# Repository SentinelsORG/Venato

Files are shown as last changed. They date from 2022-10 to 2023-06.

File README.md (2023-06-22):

# Project Venato

## What is "Venato"?

"**Venato**" is a piece of hardware that provides affordable surveillance and protection to people. The main focus of this project is to **showcase our skills in PCB design, circuit design, and RF design**. Additionally, we have taken this opportunity to create something useful for society.

<ins>**The Problem We Are Addressing**</ins>

Most surveillance systems in the market are expensive and require a complex installation procedure. At the time of developing this device, CCTV systems did not have a machine learning model to detect theft or danger. Do you have a protection or tracking system for your personal belongings, such as your wallet, travel bags, vehicle, or pets?

<ins>**The Basic Idea of Our Solution**</ins>

"Venato" is a modular device, meaning it consists of a main module (Venato Board) and other optional modules. Buyers can select the features they desire and obtain the necessary modules. The system can be upgraded using these modules. The main module (Venato) houses all the computing power, battery, and features like GPS and GPRS. The base module includes the charging station and cameras. Additionally, we are developing a few extra modules that provide additional features for this setup. The main module (i.e. Venato) is a credit card sized PCB that we designed specially for the ease of carrying. At the moment, we are still developing this module to be more compact, more featurestic and user friendly.

## Schematic Design

Please find below a brief explanation of the schematic design. I have included a screenshot of the schematic design for your reference, which is attached below. Additionally, you can access the PDF version of the schematic through the following link:

Link: [https://github.com/SentinelsORG/Venato/blob/main/documentation/schematic.pdf](https://github.com/SentinelsORG/Venato/blob/main/documentation/schematic.pdf)

The schematic illustrates the electronic design of the main PCB (Venato). As depicted, we have utilized ESP32 and SIM808 chips to provide our PCB with all the necessary functionalities. Furthermore, you can observe the incorporation of meticulous design techniques aimed at enhancing the reliability and fail-safe nature of our product.

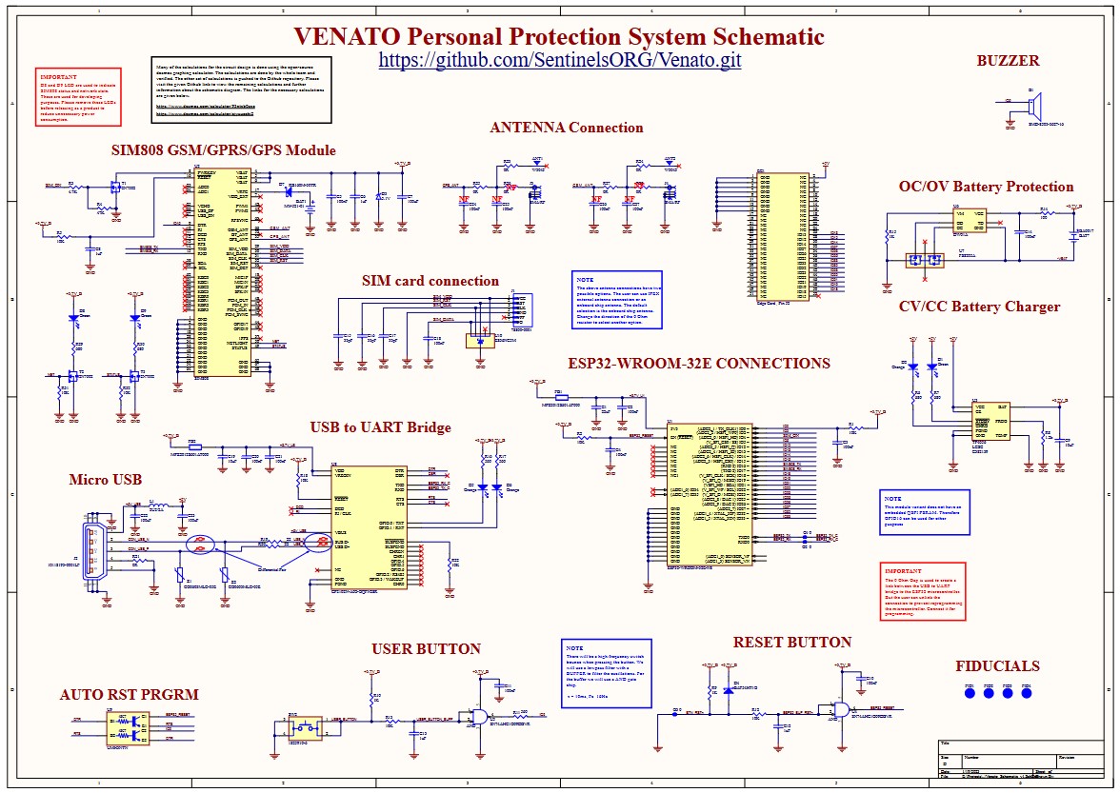
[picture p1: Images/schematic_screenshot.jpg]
Screen shot of the Schematic PDF

In addition to the previously mentioned schematic design of the main PCB, please note that we have also developed separate PCBs for the other modules. You can access the schematic designs for these modules in the provided repository.

## PCB Design

In addition to the schematic design, we have invested considerable effort in designing the PCB for this project. In this PCB design, meticulous attention has been given to the placement of each capacitor and resistor. Furthermore, we have diligently calculated the trace impedance and ensured its compatibility with the antennas employed for GPS and GSM/GPRS. A screenshot of the 2D view of the PCB design, created using Altium software, is provided below. For the original PCB and schematic designs, please refer to the corresponding repository on GitHub.

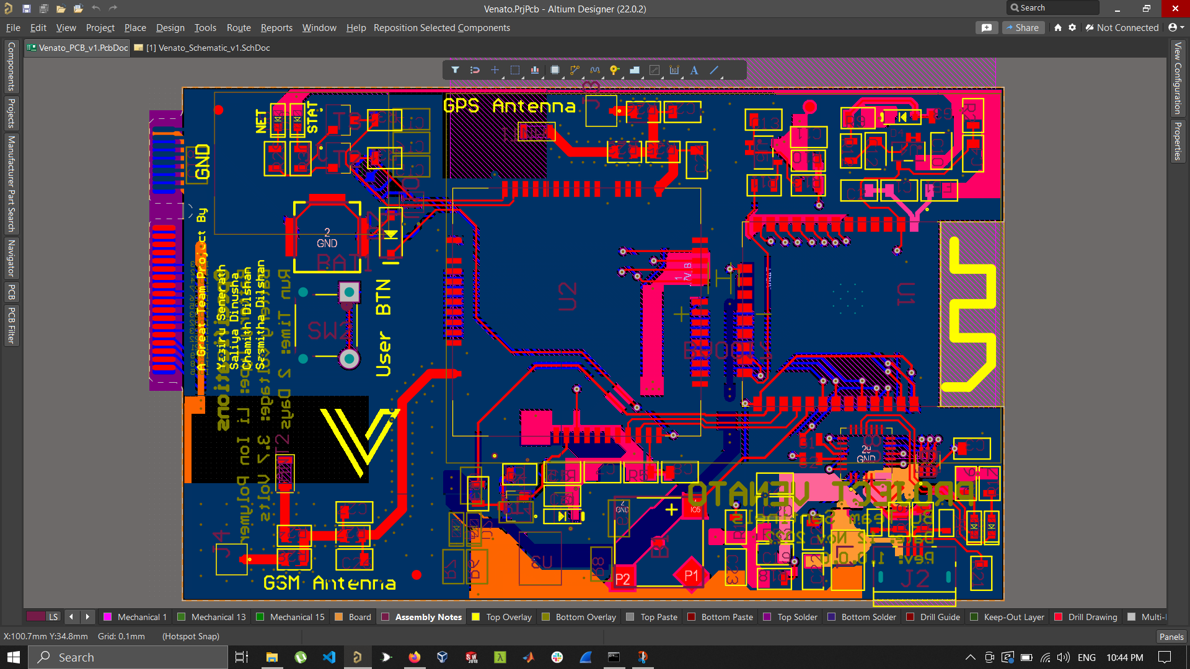
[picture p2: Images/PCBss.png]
Screen shot of 2D PCB


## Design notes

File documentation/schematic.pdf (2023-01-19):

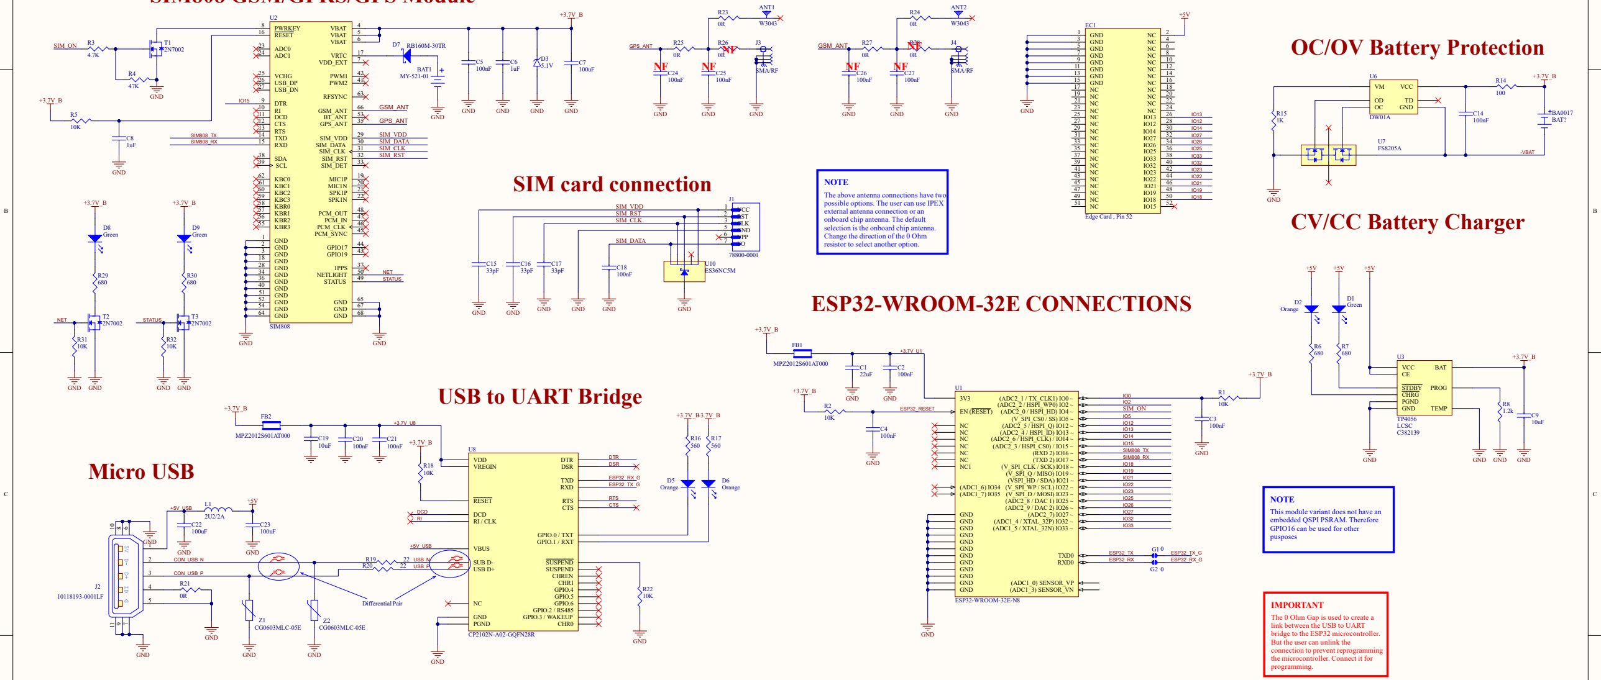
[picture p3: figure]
EN (RESET); (ADC1_0) SENSOR_VP (ADC1_3) SENSOR_VN; (ADC1_6) IO34 (ADC1_7) IO35; TXD0 RXD0; (ADC2_1 / TX_CLK1) IO0 ~; (ADC2_2 / HSPI_WP0) IO2 ~ (ADC2_0 / HSPI_HD) IO4 ~ (V_SPI_CS0 / SS) IO5 ~ (ADC2_5 / HSPI_Q) IO12 ~ (ADC2_4 / HSPI_ID) IO13 ~ (ADC2_6 / HSPI_CLK) / IO14 ~ (ADC2_3 / HSPI_CS0) / IO15 ~ (RXD 2) IO16 ~ (TXD 2) IO17 ~ (V_SPI_CLK / SCK) IO18 ~ (V_SPI_Q / MISO) IO19 ~ (VSPI_HD / SDA) IO21 ~ (V_SPI_WP / SCL) IO22 ~ (V_SPI_D / MOSI) IO23 ~ (ADC2_8 / DAC 1) IO25 ~ (ADC2_9 / DAC 2) IO26 ~ (ADC2_7) IO27 ~ (ADC1_4 / XTAL_32P) IO32 ~ (ADC1_5 / XTAL_32N) IO33 ~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
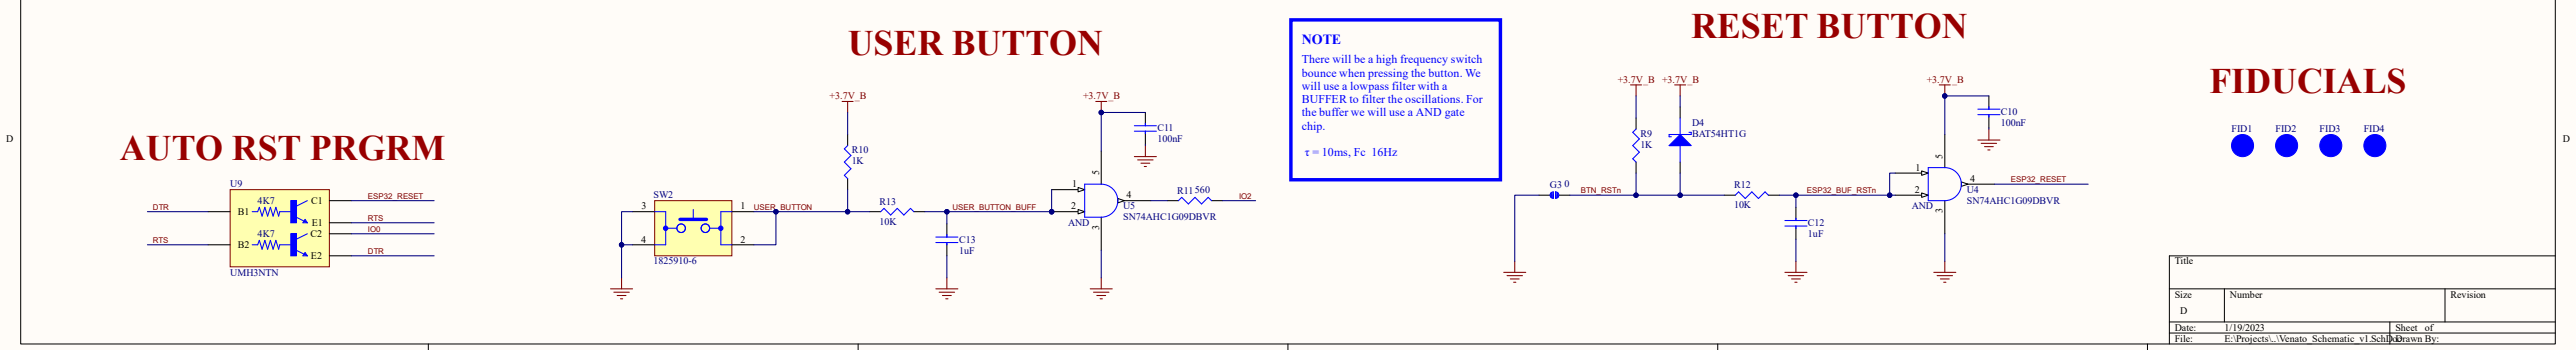
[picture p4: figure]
Title; Size; Number; Revision; Date:; Sheet of; File:; E:\Projects\..\Venato_Schematic_v1.SchDocDrawn By:; AND; U4 SN74AHC1G09DBVR; D4 BAT54HT1G; BTN_RSTn; ESP32_BUF_RSTn; ESP32_RESET; RESET BUTTON; U5 SN74AHC1G09DBVR; USER_BUTTON; USER_BUTTON_BUFF; USER BUTTON; FID1; FID2; FID3; FID4; FIDUCIALS; There will be a high frequency switch bounce when pressing the button. We will use a lowpass filter with a BUFFER to filter the oscillations. For the buffer we will use a AND gate chip.; NOTE; UMH3NTN; DTR; RTS; AUTO RST PRGRM

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
# SIM808 GSM/GPRS/GPS Module

# VENATO Personal Protection System Schematic

# https://github.com/SentinelsORG/Venato.git

# BUZZER

IO5

GND

# ANTENNA Connection

### D8 and D9 LED are used to indicate

SIM808 status and network state.

### These are used for developing purposes. Please remove these LEDs before releasing as a product to reduce unnecessary power

consumption.

## IMPORTANT

Many of the calculations for the circuit design is done using the open-source desmos graphing calculator. The calculations are done by the whole team and verified. The other set of calculations is pushed to the Github repository. Please visit the given Github link to view the remaining calculations and further information about the schematic diagram. The links for the necessary calculations

are given below.

### https://www.desmos.com/calculator/93ntxb0axe https://www.desmos.com/calculator/zjyuuzehi2

+

B1

SMD-8503-3627-16

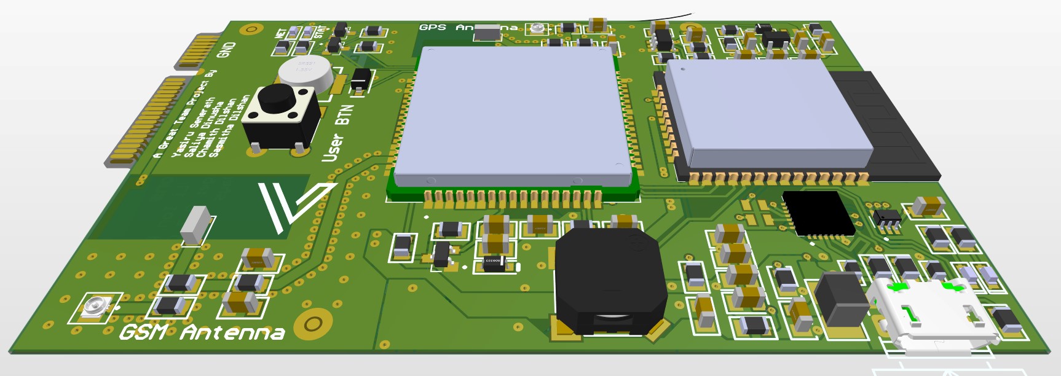
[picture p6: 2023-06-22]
Images/pcb 3D.jpg

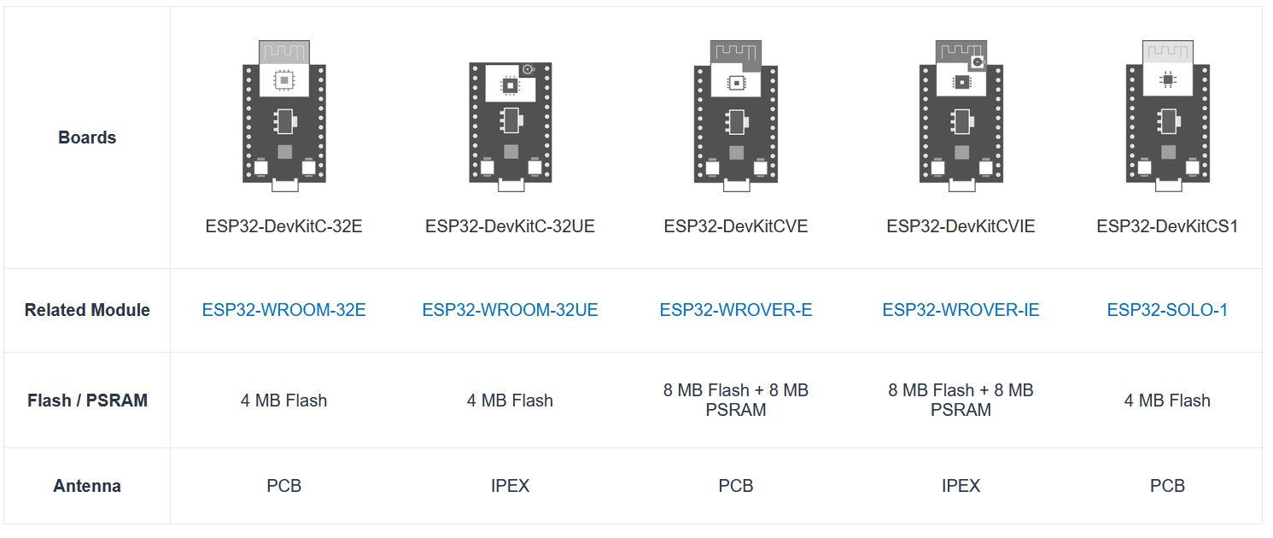
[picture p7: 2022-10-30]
Images/ESP32 Devkits.jpg

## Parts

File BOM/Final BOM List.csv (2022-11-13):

LCSC Part Number | Manufacture Part Number | Manufacturer | Package | Order Qty. | Min\Mult Order Qty. | Unit Price | Order Price | Description | Product Link
C2832999 | GD25Q80ESIG | GigaDevice Semicon Beijing | SOP-8-208mil | 1 | 1 | $0.46 | $0.46 | 2.7V~3.6V -40℃~85℃ 8Mbit 133MHz SOP-8-208mil NOR FLASH ROHS | https://assets.lcsc.com/images/lcsc/96x96/20210526_GigaDevice-Semicon-Beijing-GD25Q80ESIG_C2832999_front.jpg
C3019597 | W3043 | Pulse Elec | - | 2 | 1 | $1.52 | $3.05 | Chip antenna Vertical 50Ω - Antennas ROHS | https://assets.lcsc.com/images/lcsc/96x96/20220623_Pulse-Elec-W3043_C3019597_front.jpg
C2685545 | SMD-8503-3627-16Ω | S&S | SMD | 1 | 1 | $0.35 | $0.35 | SMD Buzzers ROHS | https://assets.lcsc.com/images/lcsc/96x96/20210121_S-S-SMD-8503-3627-16R_C2685545_front.jpg
C964848 | MY-521-01 | MYOUNG | SMD | 4 | 1 | $0.16 | $0.64 | Battery button SR521 SMD Battery Connectors ROHS | https://assets.lcsc.com/images/lcsc/96x96/20201222_MYOUNG-MY-521-01_C964848_front.jpg
C45783 | CL21A226MAQNNNE | Samsung Electro-Mechanics | 805 | 20 | 20 | $0.02 | $0.45 | 25V 22uF X5R ±20% 0805 Multilayer Ceramic Capacitors MLCC - SMD/SMT ROHS | https://assets.lcsc.com/images/lcsc/96x96/20190222_Samsung-Electro-Mechanics-CL21A226MAQNNNE_C45783_front.jpg
C77083 | GRM21BR71H105KA12L | Murata Electronics | 805 | 10 | 10 | $0.05 | $0.51 | 50V 1uF X7R ±10% 0805 Multilayer Ceramic Capacitors MLCC - SMD/SMT ROHS | https://assets.lcsc.com/images/lcsc/96x96/20180914_Murata-Electronics-GRM21BR71H105KA12L_C77083_front.jpg
C141660 | GRM21BR60J107ME15L | Murata Electronics | 805 | 3 | 1 | $0.40 | $1.21 | 6.3V 100uF X5R ±20% 0805 Multilayer Ceramic Capacitors MLCC - SMD/SMT ROHS | https://assets.lcsc.com/images/lcsc/96x96/20180914_Murata-Electronics-GRM21BR60J107ME15L_C141660_front.jpg
C107115 | CC0805JRNPO9BN330 | YAGEO | 805 | 100 | 100 | $0.01 | $0.77 | 50V 33pF NP0 ±5% 0805 Multilayer Ceramic Capacitors MLCC - SMD/SMT ROHS | https://assets.lcsc.com/images/lcsc/96x96/20200926_YAGEO-CC0805JRNPO9BN330_C107115_front.jpg
C21107 | BAT54HT1G | onsemi | SOD-323 | 10 | 10 | $0.05 | $0.51 | 30V 800mV@100mA 200mA SOD-323 Schottky Barrier Diodes (SBD) ROHS | https://assets.lcsc.com/images/lcsc/96x96/20190622_onsemi-BAT54HT1G_C21107_front.jpg
C183502 | RB160M-30TR | ROHM Semicon | SOD-123 | 5 | 5 | $0.10 | $0.50 | 30V 480mV@1A 1A SOD-123 Schottky Barrier Diodes (SBD) ROHS | https://assets.lcsc.com/images/lcsc/96x96/20180921_ROHM-Semicon-RB160M-30TR_C183502_front.jpg
C21519 | MPZ2012S601AT000 | TDK | 805 | 10 | 10 | $0.05 | $0.52 | 2A 1 100mΩ 600Ω@100MHz ±25% 0805 Ferrite Beads ROHS | https://assets.lcsc.com/images/lcsc/96x96/20180914_TDK-MPZ2012S601AT000_C21519_front.jpg
C127364 | 788000001 | MOLEX | SMD | 1 | 1 | $0.70 | $0.70 | Clamshell 1.5mm Deck MicroSIM card SMD SIM Card Connectors ROHS | https://assets.lcsc.com/images/lcsc/96x96/20180914_MOLEX-788000001_C127364_front.jpg
C132562 | 10118193-0001LF | Amphenol ICC | SMD | 3 | 1 | $0.23 | $0.69 | USB 2.0 1 Surface Mount 5 Female Micro-B SMD USB Connectors ROHS | https://assets.lcsc.com/images/lcsc/96x96/20180914_Amphenol-ICC-10118193-0001LF_C132562_front.jpg
C84376 | RC0805FR-0710KL | YAGEO | 805 | 200 | 100 | $0.00 | $0.46 | 125mW 150V ±100ppm/℃ ±1% -55℃~+155℃ 10kΩ 0805 Chip Resistor - Surface Mount ROHS | https://assets.lcsc.com/images/lcsc/96x96/20180914_YAGEO-RC0805FR-0710KL_C84376_front.jpg
C105427 | RC0805JR-074K7L | YAGEO | 805 | 100 | 100 | $0.00 | $0.20 | 125mW Thick Film Resistors 150V ±100ppm/℃ ±5% -55℃~+155℃ 4.7kΩ 0805 Chip Resistor - Surface Mount ROHS | https://assets.lcsc.com/images/lcsc/96x96/20180914_YAGEO-RC0805JR-074K7L_C105427_front.jpg
C131051 | RC0805JR-0747KL | YAGEO | 805 | 100 | 100 | $0.00 | $0.18 | 125mW Thick Film Resistors 150V ±100ppm/℃ ±5% -55℃~+155℃ 47kΩ 0805 Chip Resistor - Surface Mount ROHS | https://assets.lcsc.com/images/lcsc/96x96/20180914_YAGEO-RC0805JR-0747KL_C131051_front.jpg
C114526 | RC0805FR-071K2L | YAGEO | 805 | 100 | 100 | $0.00 | $0.23 | 125mW Thick Film Resistors 150V ±100ppm/℃ ±1% -55℃~+155℃ 1.2kΩ 0805 Chip Resistor - Surface Mount ROHS | https://assets.lcsc.com/images/lcsc/96x96/20180914_YAGEO-RC0805FR-071K2L_C114526_front_10.jpg
C95781 | RC0805FR-071KL | YAGEO | 805 | 100 | 100 | $0.00 | $0.23 | 125mW Thick Film Resistors 150V ±100ppm/℃ ±1% -55℃~+155℃ 1kΩ 0805 Chip Resistor - Surface Mount ROHS | https://assets.lcsc.com/images/lcsc/96x96/20210929_YAGEO-RC0805FR-071KL_C95781_front.jpg
C114536 | RC0805FR-07560RL | YAGEO | 805 | 100 | 100 | $0.00 | $0.23 | 125mW Thick Film Resistors 150V ±100ppm/℃ ±1% -55℃~+155℃ 560Ω 0805 Chip Resistor - Surface Mount ROHS | https://assets.lcsc.com/images/lcsc/96x96/20180914_YAGEO-RC0805FR-07560RL_C114536_front_10.jpg
C105577 | RC0805FR-07100RL | YAGEO | 805 | 100 | 100 | $0.00 | $0.23 | 125mW 150V ±100ppm/℃ ±1% -55℃~+155℃ 100Ω 0805 Chip Resistor - Surface Mount ROHS | https://assets.lcsc.com/images/lcsc/96x96/20180914_YAGEO-RC0805FR-07100RL_C105577_front.jpg
C107702 | RC0805FR-0722RL | YAGEO | 805 | 100 | 100 | $0.00 | $0.23 | 125mW Thick Film Resistors 150V ±100ppm/℃ ±1% -55℃~+155℃ 22Ω 0805 Chip Resistor - Surface Mount ROHS | https://assets.lcsc.com/images/lcsc/96x96/20180914_YAGEO-RC0805FR-0722RL_C107702_front_10.jpg
C96345 | RC0805JR-070RL | YAGEO | 805 | 100 | 100 | $0.00 | $0.19 | 125mW Thick Film Resistors 150V -55℃~+155℃ 0Ω 0805 Chip Resistor - Surface Mount ROHS | https://assets.lcsc.com/images/lcsc/96x96/20211015_YAGEO-RC0805JR-070RL_C96345_front.jpg
C428628 | 1825910-6 | TE Connectivity | Plugin | 5 | 5 | $0.07 | $0.33 | 6mm 5mm Round Button 50mA Straight 6mm SPST 24V Plugin Tactile Switches ROHS | https://assets.lcsc.com/images/lcsc/96x96/20191010_TE-Connectivity-1825910-6_C428628_front.jpg
C701342 | ESP32-WROOM-32E-N8 | Espressif Systems | SMD38,18x25.5x3.1 | 3 | 1 | $3.19 | $9.58 | SMD38,18x25.5x3.1 WiFi Modules ROHS | https://assets.lcsc.com/images/lcsc/96x96/20200727_Espressif-Systems-ESP32-WROOM-32E-N8_C701342_front.jpg
C126275 | SIM808 | SIMCom Wireless Solutions | SMD Module | 3 | 1 | $9.38 | $28.14 | SMD Module 2G/3G/4G/5G Modules ROHS | https://assets.lcsc.com/images/lcsc/96x96/20180914_SIMCom-Wireless-Solutions-SIM808_C126275_front.jpg
C725790 | TP4056 | UMW(Youtai Semiconductor Co., Ltd.) | ESOP-8 | 5 | 5 | $0.08 | $0.41 | ESOP-8 Battery Management ICs ROHS | https://assets.lcsc.com/images/lcsc/96x96/20200822_UMW-Youtai-Semiconductor-Co---Ltd--TP4056_C725790_front.jpg
C840099 | SN74AHC1G09DBVR | Texas Instruments | SOT-23-5 | 2 | 1 | $0.32 | $0.65 | 74AHC 2V~5.5V 1uA 2 1 And SOT-23-5 Gates ROHS | https://assets.lcsc.com/images/lcsc/96x96/20200919_Texas-Instruments-SN74AHC1G09DBVR_C840099_front.jpg
C351410 | DW01A | PUOLOP | SOT-23-6L | 10 | 10 | $0.04 | $0.37 | SOT-23-6L Battery Management ICs ROHS | https://assets.lcsc.com/images/lcsc/96x96/20190109_PUOLOP-DW01A_C351410_front.jpg
C16052 | FS8205A | Fortune Semicon | TSSOP-8(3x4.4x0.65） | 5 | 5 | $0.24 | $1.21 | 20V 6A 25mΩ@4.5V,4A 1W 1V@250uA 2 N-Channel TSSOP-8(3x4.4x0.65） MOSFETs ROHS | https://assets.lcsc.com/images/lcsc/96x96/20180914_Fortune-Semicon-FS8205A_C16052_front.jpg
C964632 | CP2102N-A02-GQFN28R | SILICON LABS | QFN-28 | 1 | 1 | $2.69 | $2.69 | QFN-28 USB ICs ROHS | https://assets.lcsc.com/images/lcsc/96x96/20220920_SILICON-LABS-CP2102N-A02-GQFN28R_C964632_front.jpg
C123008 | UMH3NTN | ROHM Semicon | SOT-363 | 5 | 5 | $0.07 | $0.33 | 2 NPN - Pre-Biased 150mW 100mA 50V SOT-363 Digital Transistors ROHS | https://assets.lcsc.com/images/lcsc/96x96/20180914_ROHM-Semicon-UMH3NTN_C123008_front.jpg
C2960985 | ES36NC5M | JESTEK | SOT-363 | 10 | 10 | $0.04 | $0.35 | SOT-363 ESD Protection Devices ROHS | https://assets.lcsc.com/images/lcsc/96x96/20220407_JESTEK-ES36NC5M_C2960985_front.jpg
C840634 | CG0603MLC-05E | BOURNS | 603 | 5 | 5 | $0.20 | $0.99 | 30V 0.2pF@1MHz 5V 0603 Varistors ROHS | https://assets.lcsc.com/images/lcsc/96x96/20210402_BOURNS-CG0603MLC-05E_C840634_front.jpg
C83055 | 0805B104K500CT | Walsin Tech Corp | 805 | 50 | 50 | $0.01 | $0.32 | 50V 100nF X7R ±10% 0805 Multilayer Ceramic Capacitors MLCC - SMD/SMT ROHS | https://assets.lcsc.com/images/lcsc/96x96/20200709_Walsin-Tech-Corp-0805B104K500CT_C83055_front.jpg
C2174205 | TMK212BJ105KD-T | Taiyo Yuden | 805 | 20 | 20 | $0.03 | $0.60 | 25V 1uF X5R ±10% 0805 Multilayer Ceramic Capacitors MLCC - SMD/SMT ROHS | https://assets.lcsc.com/images/lcsc/96x96/20220311_Taiyo-Yuden-TMK212BJ105KD-T_C2174205_front.jpg
C109040 | GRM21BC71E106KE11L | Murata Electronics | 805 | 50 | 5 | $0.08 | $4.23 | 25V 10uF X7S ±10% 0805 Multilayer Ceramic Capacitors MLCC - SMD/SMT ROHS | https://assets.lcsc.com/images/lcsc/96x96/20200318_Murata-Electronics-GRM21BC71E106KE11L_C109040_front.jpg
C5137310 | TC0603GF01-1CSA | TCWIN | 603 | 50 | 50 | $0.02 | $0.80 | Green 2.6V~3V 0603 Light Emitting Diodes (LED) ROHS | https://assets.lcsc.com/images/lcsc/96x96/20221107_TCWIN-TC0603GF01-1CSA_C5137310_front.jpg
C434425 | SZYY0603O | Yongyu Photoelectric | 603 | 50 | 50 | $0.01 | $0.57 | 10mA 612nm Colorless transparence -40℃~+85℃ 598nm~608nm Orange 120° 40mW 0603 Light Emitting Diodes (LED) ROHS | https://assets.lcsc.com/images/lcsc/96x96/20191211_Yongyu-Photoelectric-SZYY0603O_C434425_front.jpg
C2904813 | BZT52C5V1S | YONGYUTAI | SOD-323 | 50 | 50 | $0.02 | $0.78 | 2uA@2V 60Ω 5.1V~5.4V 200mW 5.1V SOD-323 Zener Diodes ROHS | https://assets.lcsc.com/images/lcsc/96x96/20211016_YONGYUTAI-BZT52C5V1S_C2904813_front.jpg
C92980 | CBC3225T2R2MR | Taiyo Yuden | 1210 | 5 | 5 | $0.10 | $0.48 | 1.13A 2.2uH ±20% 2A 104mΩ 1210 Inductors (SMD) ROHS | https://assets.lcsc.com/images/lcsc/96x96/20180914_Taiyo-Yuden-CBC3225T2R2MR_C92980_front.jpg
C2771101 | CQ05W8F6800T5E | UNI-ROYAL(Uniroyal Elec) | 805 | 100 | 100 | $0.00 | $0.37 | 125mW ±100ppm/℃ ±1% -55℃~+155℃ 680Ω 0805 Chip Resistor - Surface Mount ROHS | https://assets.lcsc.com/images/lcsc/96x96/20221008_UNI-ROYAL-Uniroyal-Elec-CQ05W8F6800T5E_C2771101_front.jpg
C382335 | 2N7002K | KEXIN | SOT-23 | 20 | 20 | $0.02 | $0.44 | 60V 300mA 2Ω@10V,500mA 350mW 2.5V@1mA N Channel SOT-23 MOSFETs ROHS | https://assets.lcsc.com/images/lcsc/96x96/20190704_KEXIN-2N7002K_C382335_front.jpg
C2987682 | IPEX-1 | ZIISOR | SMD | 10 | 10 | $0.05 | $0.51 | SMD RF Connectors / Coaxial Connectors ROHS | https://assets.lcsc.com/images/lcsc/96x96/20220710_ZIISOR-IPEX-1_C2987682_front.jpg
C565575 | FN21N180J500PAG | PSA(Prosperity Dielectrics) | 805 | 50 | 50 | $0.01 | $0.32 | 50V 18pF C0G ±5% 0805 Multilayer Ceramic Capacitors MLCC - SMD/SMT ROHS | https://assets.lcsc.com/images/lcsc/96x96/20201121_PSA-Prosperity-Dielectrics-FN21N180J500PAG_C565575_front.jpg
C336527 | EEE1AA101WR | PANASONIC | SMD,D5xL5.4mm | 5 | 5 | $0.21 | $1.03 | -40℃~+85℃ 2000hrs@85℃ 100uF 5.4mm 10V 5mm ±20% SMD,D5xL5.4mm Aluminum Electrolytic Capacitors - SMD ROHS | https://assets.lcsc.com/images/lcsc/96x96/20221012_PANASONIC-EEE1AA101WR_C336527_front.jpg
C428486 | 1775862-2 | TE Connectivity | SMD,P=0.8mm | 2 | 1 | $0.52 | $1.04 | 0.8mm Surface Mount 52 SMD,P=0.8mm Card Edge Connectors ROHS | https://assets.lcsc.com/images/lcsc/96x96/20191011_TE-Connectivity-1775862-2_C428486_front.jpg
C124384 | B-2100S06P-B110 | Ckmtw(Shenzhen Cankemeng) | Straight,P=2.54mm | 10 | 10 | $0.04 | $0.39 | Straight 2.54mm 6mm -40℃~+105℃ 2 3mm 6 2.54mm Black Brass 2x3P 2.54mm Straight,P=2.54mm Pin Headers ROHS | https://assets.lcsc.com/images/lcsc/96x96/20180914_Ckmtw-Shenzhen-Cankemeng-B-2100S06P-B110_C124384_front.jpg
C202111 | DM3CS-SF | HRS(Hirose) | SMD | 1 | 1 | $0.94 | $0.94 | Deck MicroSD card (TF card) Pluggable SMD SD Card Connectors ROHS | https://assets.lcsc.com/images/lcsc/96x96/20180914_HRS-Hirose-DM3CS-SF_C202111_front.jpg
C132125 | DS1023-2*9SF11 | CONNFLY Elec | Straight,P=2.54mm | 2 | 1 | $0.16 | $0.32 | 2.54mm 2.54mm Straight 2x9P 18 2 Straight,P=2.54mm Female Headers ROHS | https://assets.lcsc.com/images/lcsc/96x96/20180914_CONNFLY-Elec-DS1023-2-9SF11_C132125_front.jpg
C168677 | 68000-103HLF | Amphenol ICC | Straight,P=2.54mm | 3 | 1 | $0.23 | $0.69 | Straight Square Pins 2.54mm 1 2.54mm Black Phosphor bronze Straight,P=2.54mm Pin Headers ROHS | https://assets.lcsc.com/images/lcsc/96x96/20180914_Amphenol-ICC-68000-103HLF_C168677_front.jpg
C96346 | RC0805FR-07100KL | YAGEO | 805 | 100 | 100 | $0.00 | $0.23 | 125mW 150V ±100ppm/℃ ±1% -55℃~+155℃ 100kΩ 0805 Chip Resistor - Surface Mount ROHS | https://assets.lcsc.com/images/lcsc/96x96/20190628_YAGEO-RC0805FR-07100KL_C96346_front.jpg
C107700 | RC0805FR-071ML | YAGEO | 805 | 100 | 100 | $0.00 | $0.24 | 125mW 150V ±100ppm/℃ ±1% -55℃~+155℃ 1MΩ 0805 Chip Resistor - Surface Mount ROHS | https://assets.lcsc.com/images/lcsc/96x96/20180914_YAGEO-RC0805FR-071ML_C107700_front_10.jpg
C132230 | ATMEGA328PB-AU | Microchip Tech | TQFP-32_7x7x08P | 1 | 1 | $2.59 | $2.59 | TQFP-32_7x7x08P Microcontroller Units (MCUs/MPUs/SOCs) ROHS | https://assets.lcsc.com/images/lcsc/96x96/20221017_Microchip-Tech-ATMEGA328PB-AU_C132230_front.jpg
C173386 | AMS1117-3.3V | Shenzhen Fuman Elec | SOT-223 | 5 | 5 | $0.06 | $0.32 | 75dB@(10kHz) 800mA 1.5V@(700mA) Fixed 3.3V~3.3V Positive 1 12V SOT-223 Linear Voltage Regulators (LDO) ROHS | https://assets.lcsc.com/images/lcsc/96x96/20220413_Shenzhen-Fuman-Elec-AMS1117-3-3V_C173386_front.jpg
C596821 | ABLS-16.000MHZ-B4-T | Abracon LLC | HC-49S-SMD-2P | 2 | 1 | $0.32 | $0.65 | 16MHz 18pF 40Ω ±30ppm ±50ppm -20℃~+70℃ HC-49S-SMD-2P Crystals ROHS | https://assets.lcsc.com/images/lcsc/96x96/20220325_Abracon-LLC-ABLS-16-000MHZ-B4-T_C596821_front.jpg
 |  |  |  |  | SUB TOTAL |  | $75.45

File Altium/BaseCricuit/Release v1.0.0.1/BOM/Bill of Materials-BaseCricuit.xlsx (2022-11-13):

 | Bill of Materials
 |  |  |  |  |  |  | 2175 Salk Avenue
 | Project Title: | Bill of Materials for Project [BaseCricuit.PrjPcb] (No PCB Document Selected) |  |  |  |  | Suite 200
 | Project File Name: | BaseCricuit.PrjPcb |  |  |  |  | Carlsbad, CA 92008
 | Assembly Variant: | None |  |  |  |  | USA
Part Number | Description | Designator | Manufacture | Manufacture Part Number | Supplier | Supplier Part Number | Supplier Unit Price | Quantity
CGA4J2X7R1H104K125AM | Cap Ceramic 0.1uF 50V X7R 10% Pad SMD 0805 125°C Automotive T/R | C1, C3, C6, C8 | TDK | CGA4J2X7R1H104K125AM | Digi-Key | 445-6958-1-ND | $0.20 | 4
CGA4J3X7S1A106M125AB | Cap Ceramic 10uF 10V X7S 20% Pad SMD 0805 125°C Low ESR Automotive T/R | C2, C4, C5 | TDK | CGA4J3X7S1A106M125AB | Digi-Key | 445-16115-1-ND | $0.41 | 3
C0805C180J5GACTU | Cap Ceramic 18pF 50V C0G 5% SMD 0805 125C Paper T/R | C7, C9 | KEMET | C0805C180J5GACTU | Digi-Key | 399-C0805C180J5GAC7800CT-ND | $0.11 | 2
EEE-1AA101WR | Cap Aluminum 100uF 10V 20% (5 X 5.4mm) SMD 50mA 1000 hr 85°C T/R | C10, C11, C12, C13 | Panasonic | EEE-1AA101WR | RSComponents | 1763738 |  | 4
RB160M-30TR | DIODE SCHOTTKY 30V 1A PMDU | D1 |  |  |  |  |  | 1
MPZ2012S601AT000 | Ferrite Beads Multi-Layer Power 600Ohm 25% 100MHz 2A 100mOhm DCR 0805 T/R | FB1, FB2 | TDK | MPZ2012S601AT000 | Digi-Key | 445-2206-6-ND |  | 2
0Ohm gap | This is a gap that diconects line. you can connect it using soldier | G1, G2 |  |  |  |  |  | 2
1775862-2 | MSATA/MINI PCI-E 5.2H TYPE I G/F | J1, J2 | TE Connectivity | 1775862-2 | RSComponents | 2411326P |  | 2
SCREW_TERMINAL | SCREW_TERMINAL | J3 |  |  |  |  |  | 1
67997-106HLF | Conn Unshrouded Header HDR 6 POS 2.54mm Solder ST Top Entry Thru-Hole BergStik® Bulk | J4, J6 | Amphenol Communications Solutions | 67997-106HLF | Newark | 06M1758 | $0.68 | 2
DM3CS-SF | Connector, Memory, Micro Sd, Hinged Rohs Compliant: Yes | J5 | Hirose | DM3CS-SF | RSComponents | 7726787 |  | 1
10118193-0001LF | FCI Right Angle Surface Mount Mount Female USB Connector; 100 V ac; 1.8A | J7 | Amphenol Communications Solutions | 101181930001LF | Digi-Key | 609-4616-1-ND | $0.45 | 1
PPTC092LFBN-RC | Connector Header 18 Position 0.100" (2.54mm) Tin Through Hole | J8 | Sullins | PPTC092LFBN-RC | Digi-Key | S7077-ND | $1.09 | 1
68000-103HLF | Conn Unshrouded Header HDR 3 POS 2.54mm Solder ST Top Entry Thru-Hole BergStik® Automotive Bulk | JP1 | Amphenol Communications Solutions | 68000-103HLF | Allied Electronics | 70236888 | $0.28 | 1
L1210R2R2MDWIT | Inductor RF Chip Wirewound 2.2uH 20% 100KHz 1.13A 0.104Ohm DCR 1210 T/R | L1 | KEMET | L1210R2R2MDWIT | Digi-Key | 399-9598-1-ND | $0.48 | 1
RC0805JR-074K7L | Res Thick Film 0805 4.7K Ohm 5% 0.125W(1/8W) ±100ppm/C Pad SMD T/R | R1, R10, R11 |  |  | RSComponents |  |  | 3
RC0805FR-07100KL | Res Thick Film 0805 100K Ohm 1% 1/8W ±100ppm/°C Molded SMD Paper T/R | R2 | Yageo | RC0805FR-07100KL | RSComponents | 1995648 |  | 1
RC0805FR-0722RL | Res SMD 0805 22R 1% 0.125W T.C.100PPM | R3 | Yageo | RC0805FR-0722RL | Digi-Key | 311-22.0CRCT-ND | $0.10 | 1
RC0805FR-0710KL | Res SMD 0805 10K 1% 0.125W T.C.100PPM | R4, R5, R6, R9 | Yageo | RC0805FR-0710KL | Digi-Key | 311-10.0KCRTR-ND |  | 4
RC0805FR-071ML | Res Thick Film 0805 1M Ohm 1% 0.125W(1/8W) ±100ppm/C Pad SMD T/R | R7 | Yageo | RC0805FR-071ML | Digi-Key | 311-1.00MCRCT-ND | $0.10 | 1
RC0805JR-070RL | RC Series 0805 0.125 W 0 Ohm Jumper Surface Mount Thick Film Chip Resistor | R8 | Yageo | RC0805JR-070RL | Digi-Key | 311-0.0ARCT-ND | $0.10 | 1
Relay |  | RE1 |  |  |  |  |  | 1
2N7002 | Transistor Mosfet N-ch 60V 0.3A 3-PIN SOT-23 T/r | T1 |  |  |  |  |  | 1
ATMEGA328PB-AU | IC MCU 8BIT 32KB FLASH 32TQFP | U1 | Microchip | ATMEGA328PB-AU | Mouser | 556-ATMEGA328PB-AU | $1.72 | 1
AMS1117-3.3 | Fixed Positive LDO Regulator, 3.3V, 1.3V Dropout, PDSO3 | U2 | Advanced Monolithic Systems | AMS1117-3.3 | LCSC | C6186 |  | 1
ABLS-16.000MHZ-B4-T | Crystal 16MHz ±30ppm (Tol) ±50ppm (Stability) 18pF FUND 40Ohm 2-Pin HC-49/US SMD T/R | Y1 | Abracon | ABLS-16.000MHZ-B4-T | RSComponents | 1710560 |  | 1
 |  |  |  |  |  |  | $5.72 | 44
Approved |  | Notes

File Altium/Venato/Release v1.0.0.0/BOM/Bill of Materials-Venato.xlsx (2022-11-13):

 | Bill of Materials
 |  |  |  |  |  |  | 2175 Salk Avenue
 | Project Title: | Bill of Materials for Project [Venato.PrjPcb] (No PCB Document Selected) |  |  |  |  | Suite 200
 | Project File Name: | Venato.PrjPcb |  |  |  |  | Carlsbad, CA 92008
 | Assembly Variant: | None |  |  |  |  | USA
Part Number | Description | Designator | Manufacture | Manufacture Part Number | Supplier | Supplier Part Number | Supplier Unit Price | Quantity
W3043 | Antenna Ceramic Monopole 4dB Gain 2483.5MHz SMD | ANT1, ANT2 | Pulse | W3043 | Digi-Key | 553-W3043CT-ND | $1.59 | 2
SMD-8503-3627-16 | SMD Buzzers ROHS | B1 | S&S | SMD-8503-3627-16 | LCSC | C2685545 | $0.33 | 1
BA0017 | 3.7V 1200mAh Lipo Battery. Dimension: 40.0±3.0mm x 30.0±2.0mm 8.0±0.5mm (1.575±0.118" x 1.181±0.079" x 0.315±0.020") | BA0017 |  |  |  |  |  | 1
MY-521-01 | Battery button SR521 SMD Battery Connectors ROHS | BAT1 | MYoung | MY-521-01 | LCSC | C964848 | $0.16 | 1
CL21A226MAQNNNE | CAP CER 22UF 25V X5R 0805 | C1 | Samsung | CL21A226MAQNNNE | LCSC | C45783 |  | 1
CGA4J2X7R1H104K125AM | Cap Ceramic 0.1uF 50V X7R 10% Pad SMD 0805 125°C Automotive T/R | C2, C3, C4, C5, C10, C11, C14, C18, C20, C21, C24, C25, C26, C27 | TDK | CGA4J2X7R1H104K125AM | Digi-Key | 445-6958-1-ND | $0.14 | 14
GRM21BR71H105KA12L | 0805 1 uF 50 V ±10% Tolerance X7R Multilayer Ceramic Chip Capacitor | C6 |  |  | Newark |  |  | 1
GRM21BR60J107ME15L | 0805 100 uF 6.3 V ±20% Tolerance X5R Multilayer Ceramic Chip Capacitor | C7, C22, C23 | Murata | GRM21BR60J107ME15L | Digi-Key | 490-13981-1-ND | $1.15 | 3
C2012X5R1E105K125AA | TDK - C2012X5R1E105K125AA - SMD Multilayer Ceramic Capacitor, 1 µF, 25 V, 0805 [2012 Metric], ± 10%, X5R, C Series | C8, C12, C13 | TDK | C2012X5R1E105K125AA | Digi-Key | 445-1419-1-ND | $0.21 | 3
CGA4J3X7S1A106M125AB | Cap Ceramic 10uF 10V X7S 20% Pad SMD 0805 125°C Low ESR Automotive T/R | C9, C19 | TDK | CGA4J3X7S1A106M125AB | Digi-Key | 445-16115-1-ND | $0.41 | 2
CC0805JRNPO9BN330 | Cap Ceramic 33pF 50V C0G 5% SMD 0805 125C T/R | C15, C16, C17 | Yageo | CC0805JRNPO9BN330 | Digi-Key | 311-1105-1-ND | $0.10 | 3
LGL29K-G2J1-24-Z | LED Single Chip Green 570nm 20mA 2-Pin 0603 T/R | D1, D8, D9 | Osram Opto | LGL29K-G2J1-24-Z | Bison Technologies | LGL29K-G2J1-24-Z-299157-OSRAMOPTO |  | 3
LOL29K-H2K1-24-Z | Smartled Orange Lc | D2, D5, D6 | Osram Opto | LOL29K-H2K1-24-Z | Arrow Electronics | LO L29K-H2K1-24-Z |  | 3
BZT52C5V1S | Zener Single Diode, 5.1 V, 200 Mw, Sod-323, 6 %, 2, 150 C Rohs Compliant: Yes | D3 | Multicomp | BZT52C5V1S | Farnell | 1466019 |  | 1
BAT54HT1G | Small Signal Schottky Diode, Single, 30 V, 200 Ma, 800 Mv, 600 Ma, 150 C | D4 | ON Semiconductor / Fairchild | BAT54HT1G | Digi-Key | BAT54HT1GOSDKR-ND | $0.24 | 1
RB160M-30TR | DIODE SCHOTTKY 30V 1A PMDU | D7 |  |  |  |  |  | 1
EdgeCard |  | EC1 |  |  |  |  |  | 1
MPZ2012S601AT000 | Ferrite Beads Multi-Layer Power 600Ohm 25% 100MHz 2A 100mOhm DCR 0805 T/R | FB1, FB2 | TDK | MPZ2012S601AT000 | Digi-Key | 445-2206-6-ND |  | 2
0Ohm gap | This is a gap that diconects line. you can connect it using soldier | G1, G2, G3 |  |  |  |  |  | 3
78800-0001 | Vertical Surface Mount Memory & SIM Card Connector; with SMT Termination | J1 |  |  | RSComponents |  |  | 1
10118193-0001LF | FCI Right Angle Surface Mount Mount Female USB Connector; 100 V ac; 1.8A | J2 | Amphenol Communications Solutions | 101181930001LF | Digi-Key | 609-4616-1-ND | $0.45 | 1
Ipex | SMD RF Connectors / Coaxial Connectors ROHS | J3, J4 |  |  |  |  |  | 2
L1210R2R2MDWIT | Inductor RF Chip Wirewound 2.2uH 20% 100KHz 1.13A 0.104Ohm DCR 1210 T/R | L1 | KEMET | L1210R2R2MDWIT | Digi-Key | 399-9598-1-ND | $0.48 | 1
RC0805FR-0710KL | Res SMD 0805 10K 1% 0.125W T.C.100PPM | R1, R2, R5, R12, R13, R18, R22, R31, R32 | Yageo | RC0805FR-0710KL | Digi-Key | 311-10.0KCRTR-ND |  | 9
RC0805JR-074K7L | Res Thick Film 0805 4.7K Ohm 5% 0.125W(1/8W) ±100ppm/C Pad SMD T/R | R3 |  |  | RSComponents |  |  | 1
RC0805JR-0747KL | Res Thick Film 0805 47K Ohm 5% 1/8W Ý100ppm/ÝC SMD Paper T/R | R4 |  |  | Arrow Electronics |  |  | 1
RMCF0805JT680R | Res Thick Film 0805 680 Ohm 5% 0.125W(1/8W) ±200ppm/C Pad SMD Automotive T/R | R6, R7, R29, R30 | Stackpole Electronics | RMCF0805JT680R | Digi-Key | RMCF0805JT680RCT-ND | $0.10 | 4
RC0805FR-071K2L | Res Thick Film 0805 1.2K Ohm 1% 0.125W(1/8W) ±100ppm/C Pad SMD T/R | R8 | Yageo | RC0805FR-071K2L | Mouser | 603-RC0805FR-071K2L | $0.10 | 1
RC0805FR-071KL | Res Thick Film 0805 1KOhm 1% 0.125W(1/8W) 100ppm/C Epoxy Pad SMD T/R | R9, R10, R15 | Yageo | RC0805FR-071KL | Digi-Key | 311-1.00KCRTR-ND |  | 3
RC0805FR-07560RL | Res General Purpose Thick Film 0805 560 Ohm 1% 1/8W ±100ppm/°C Molded Paper T/R | R11, R16, R17 | Yageo | RC0805FR-07560RL | Digi-Key | 311-560CRCT-ND | $0.10 | 3
RC0805FR-07100RL | Res Thick Film 0805 100 Ohm 1% 1/8W ±100ppm/°C Molded SMD Paper T/R | R14 | Yageo | RC0805FR-07100RL | Mouser | 603-RC0805FR-07100RL | $0.13 | 1
RC0805FR-0722RL | Res SMD 0805 22R 1% 0.125W T.C.100PPM | R19, R20 | Yageo | RC0805FR-0722RL | Digi-Key | 311-22.0CRCT-ND | $0.10 | 2
RC0805JR-070RL | RC Series 0805 0.125 W 0 Ohm Jumper Surface Mount Thick Film Chip Resistor | R21, R23, R24, R25, R26, R27, R28 | Yageo | RC0805JR-070RL | Digi-Key | 311-0.0ARCT-ND | $0.10 | 7
1825910-6 | Switch Tactile OFF (ON) SPST Round Button PC Pins 0.05A 24VDC 1.57N Thru-Hole Loose | SW2 | TE Connectivity | FSM4JH | Digi-Key | 450-1650-ND | $0.13 | 1
2N7002 | Transistor Mosfet N-ch 60V 0.3A 3-PIN SOT-23 T/r | T1, T2, T3 |  |  |  |  |  | 3
ESP32-WROOM-32E-N8 | 2.4 GHz WiFi + Bluetooth ® + Bluetooth LE module Built around ESP32 series of SoCs, Xtensa® dualcore 32bit LX6 microprocessor 4/8/16 MB flash available 26 GPIOs, rich set of peripherals Onboard PCB antenna or external antenna connector | U1 | Espressif Systems | ESP32-WROOM-32E-N8 | Digi-Key | 1965-ESP32-WROOM-32E-N8CT-ND | $3.30 | 1
SIM808 | GSM/GPRS + GPS + Bluetooth Module SIM808 S2-1060C-Z1F05 SIMCOM; 850/900/1800/1900MHz | U2 |  |  |  |  |  | 1
TP4056 | Res Thick Film 0805 1.2K Ohm 1% 0.125W(1/8W) ±100ppm/C Pad SMD T/R | U3 | TPOWER | TP4056 | LCSC | C382139 |  | 1
SN74AHC1G09DBVR | Single 2-input, 2-V to 5.5-V AND gate with open-drain outputs 5-SOT-23 -55 to 125 | U4, U5 | Texas Instruments | SN74AHC1G09DBVR | Digi-Key | 296-29202-1-ND |  | 2
DW01A | SOT-23-6L Battery Management ICs ROHS | U6 | TF | DW01A | LCSC | C436931 |  | 1
FS8205A | 输入电容(Ciss@Vds)：466pF 10V 反向传输电容(Crss@Vds)：58pF 10V 功率(Pd)：1.5W 阈值电压(Vgs(th)@Id)：700mV 250uA 导通电阻(RDS(on)@Vgs,Id)：19.5mΩ 4.5V,3A 栅极电荷(Qg@Vgs)：5.7nC 10V 漏源电压(Vdss)：20V 连续漏极电流(Id)：6A 工作温度(最大值)：+150℃ (Tj) 工作温度(最小值)：-55℃ (Tj) 类型：2个N沟道 | U7 | Tech Public | FS8205A | LCSC | C2830320 |  | 1
CP2102N-A02-GQFN28R | Full Speed USB to UART Bridge USB 2.0 3.3V T/R Automotive 28-Pin QFN EP | U8 | Silicon Labs | CP2102N-A02-GQFN28R | Mouser | 634-CP2102NA02QFN28R | $2.27 | 1
UMH3NTN | TRANS 2NPN PREBIAS 0.15W UMT6 | U9 | Rohm | UMH3NTN | Digi-Key | UMH3NTNCT-ND | $0.48 | 1
ES36NC5M | SOT-363 ESD Protection Devices ROHS | U10 | JESTEK | ES36NC5M | LCSC | C2960985 |  | 1
CG0603MLC-05E | ESD Suppressor Multilayer Varistor 5V Automotive 2-Pin Case 0603(1608Metric) T/R | Z1, Z2 | Bourns | CG0603MLC-05E | Digi-Key | CG0603MLC-05ETR-ND |  | 2
 |  |  |  |  |  |  | $12.07 | 100
Approved |  | Notes

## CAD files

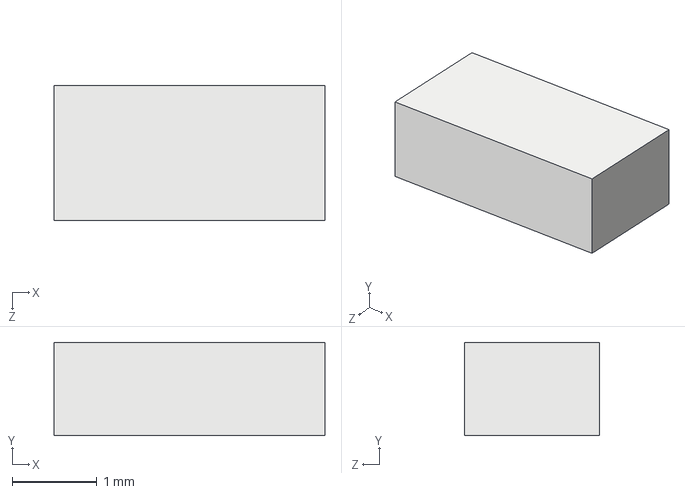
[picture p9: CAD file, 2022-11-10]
3d Models/w3043.STEP
3.20 x 1.10 x 1.60 mm

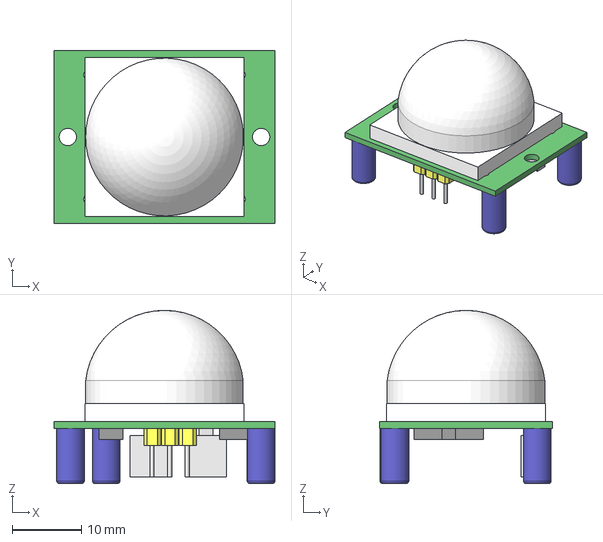
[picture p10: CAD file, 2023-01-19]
Solidworks/Base_part/HCSR501.step
32.0 x 25.0 x 25.1 mm

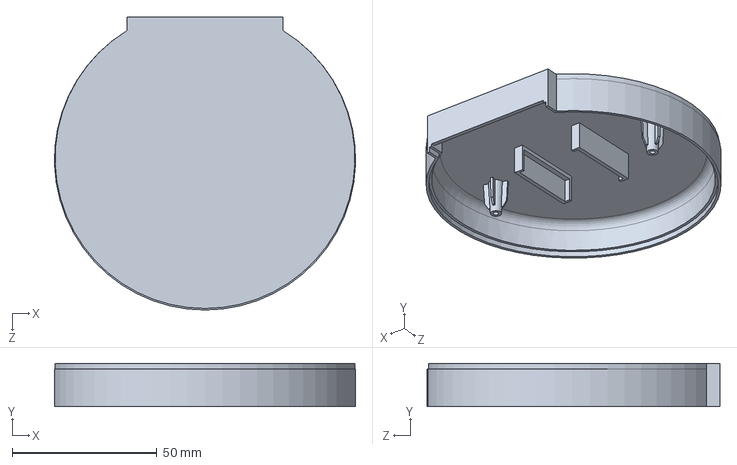
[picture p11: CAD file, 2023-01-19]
Solidworks/Venato_part/venato_top.SLDPRT
103.9 x 15.0 x 101.2 mm

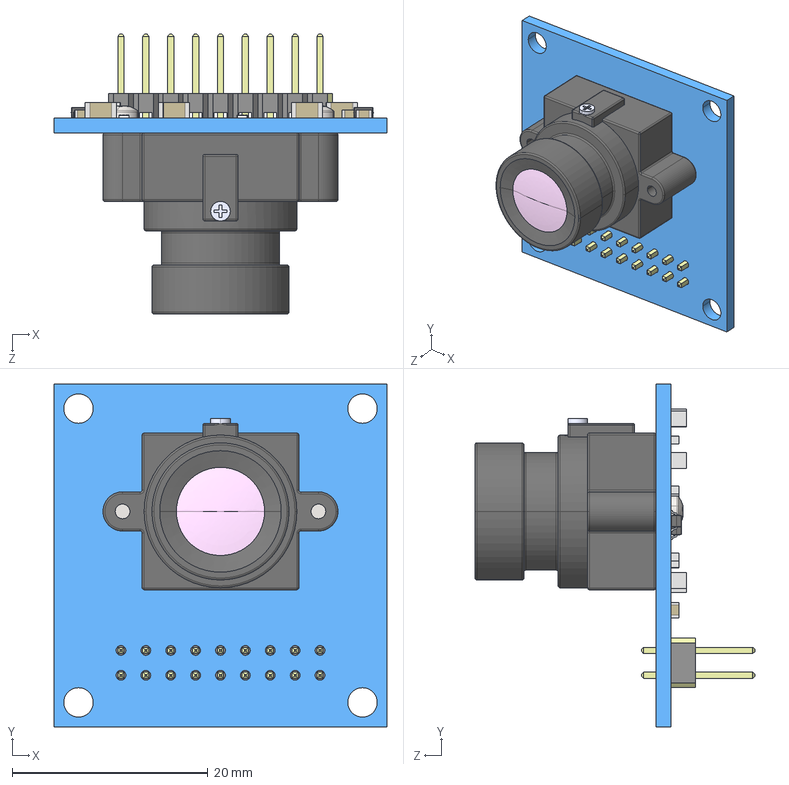
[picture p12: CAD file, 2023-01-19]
Solidworks/Base_part/Camera OV7670.STEP
34.0 x 35.0 x 28.6 mm
PcbForCamera
CameraLens
pan head cross recess screw_iso_ISO 7045 - M1.6 x 6 - Z - 6N x 2
PLS (DS1021-2xN)_DS1021-2x9
CAP 1206_�� 㬮�砭�� x 5
CAP 0603_�� 㬮�砭�� x 6
Stackpole CSR0402 Res_�� 㬮�砭�� x 3
SC-70-5_�� 㬮�砭�� x 2

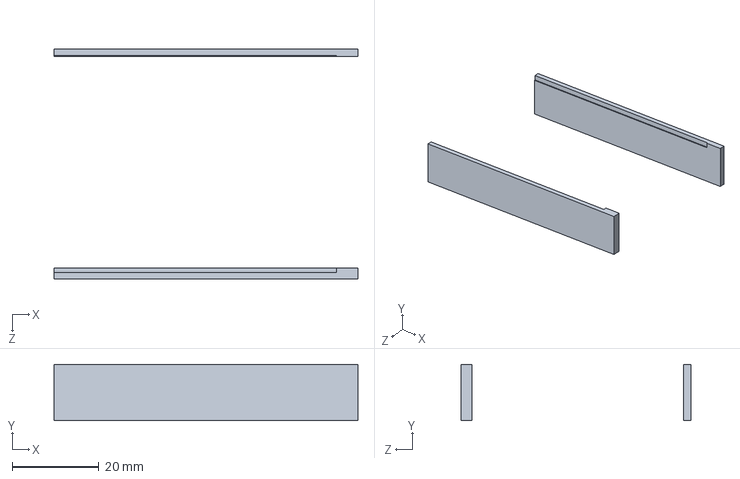
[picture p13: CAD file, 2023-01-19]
Solidworks/Venato_part/venato_pcb_holder.SLDPRT
70.0 x 13.0 x 53.0 mm

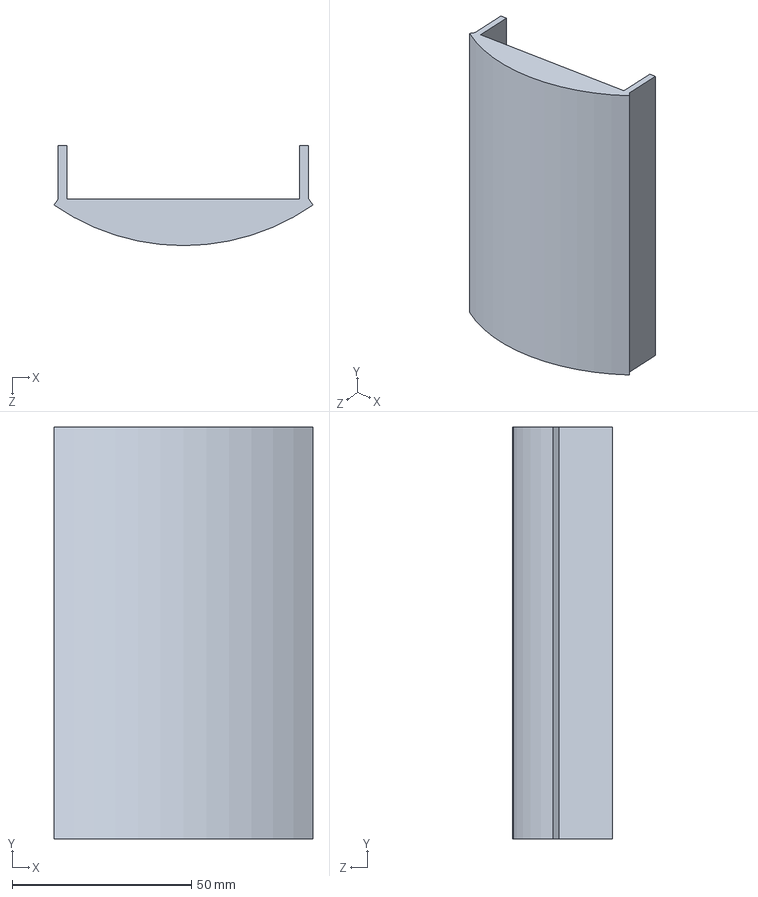
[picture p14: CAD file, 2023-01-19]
Solidworks/Base_part/Base_solidworks_top.SLDPRT
72.3 x 115.0 x 28.0 mm

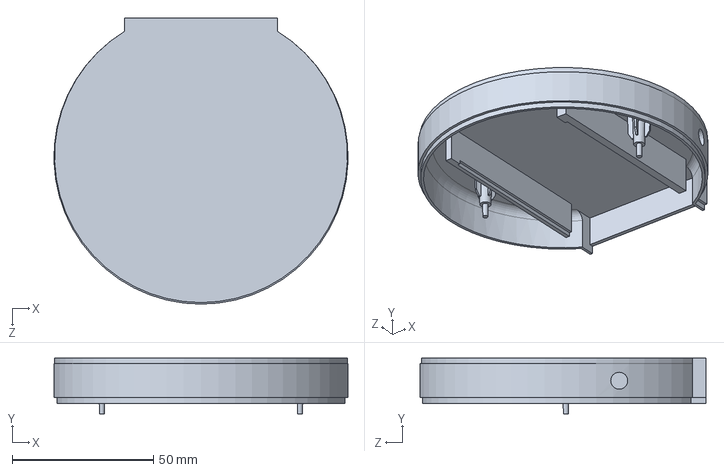
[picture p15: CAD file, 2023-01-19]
Solidworks/Venato_part/venato_bottom.SLDPRT
103.9 x 19.7 x 101.2 mm

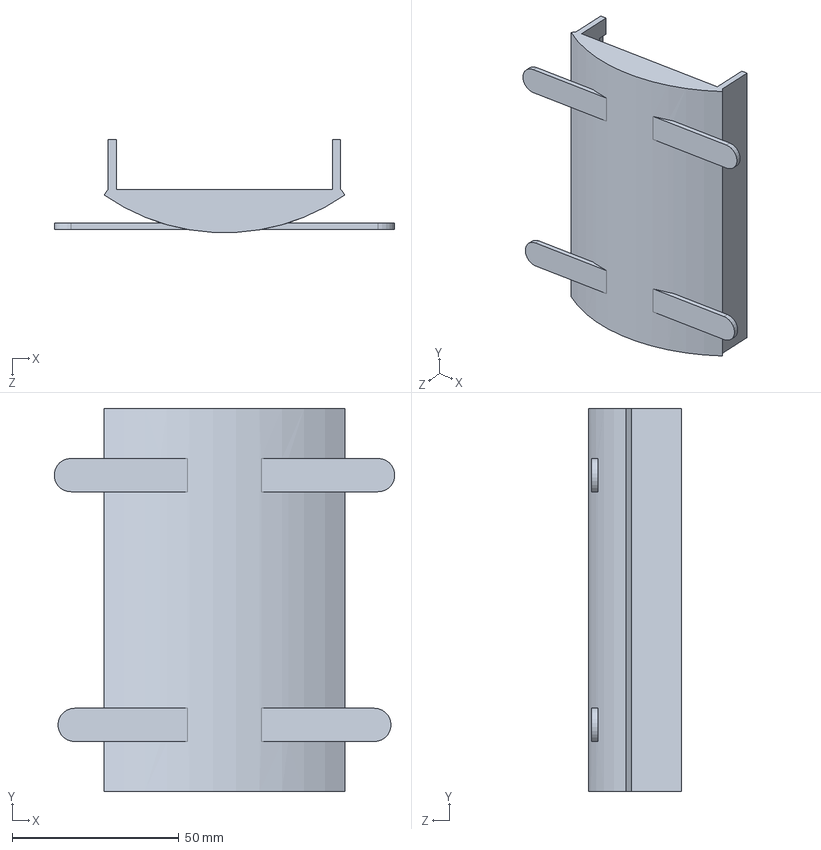
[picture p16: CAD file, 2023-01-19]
Solidworks/Base_part/Base_solidworks.SLDPRT
102.2 x 115.0 x 27.9 mm

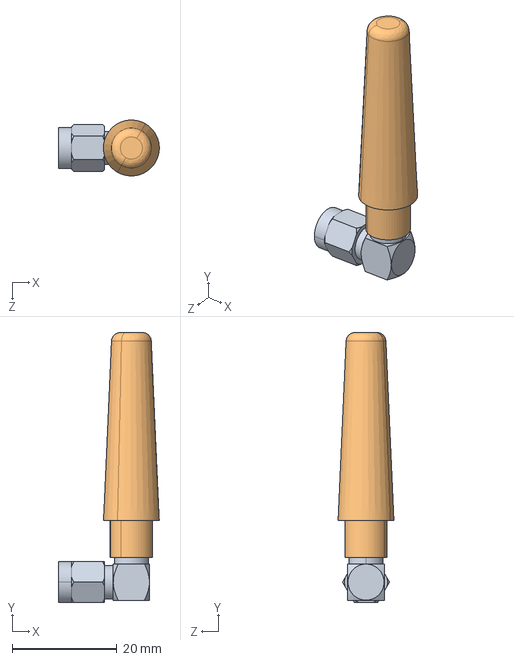
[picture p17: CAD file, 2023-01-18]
Solidworks/Venato_part/GSM ANTENNA.STEP
19.3 x 51.7 x 10.7 mm

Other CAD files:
3d Models/w3043.SLDPRT

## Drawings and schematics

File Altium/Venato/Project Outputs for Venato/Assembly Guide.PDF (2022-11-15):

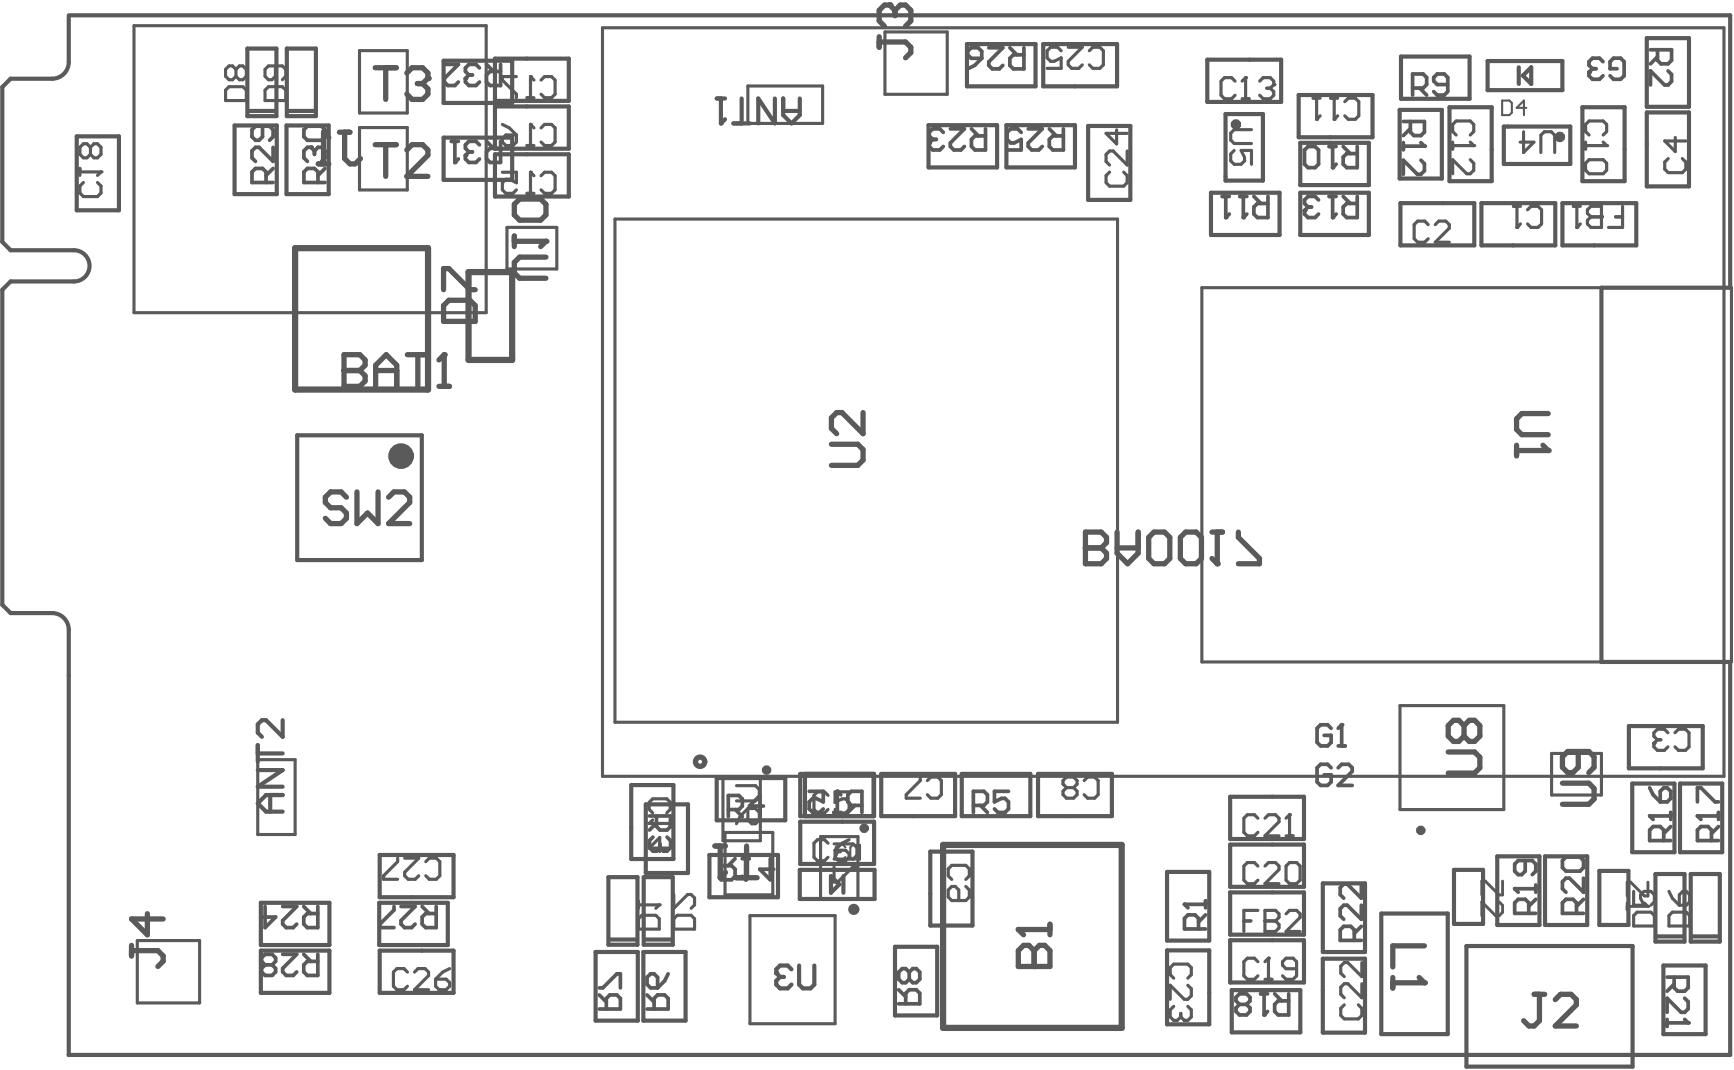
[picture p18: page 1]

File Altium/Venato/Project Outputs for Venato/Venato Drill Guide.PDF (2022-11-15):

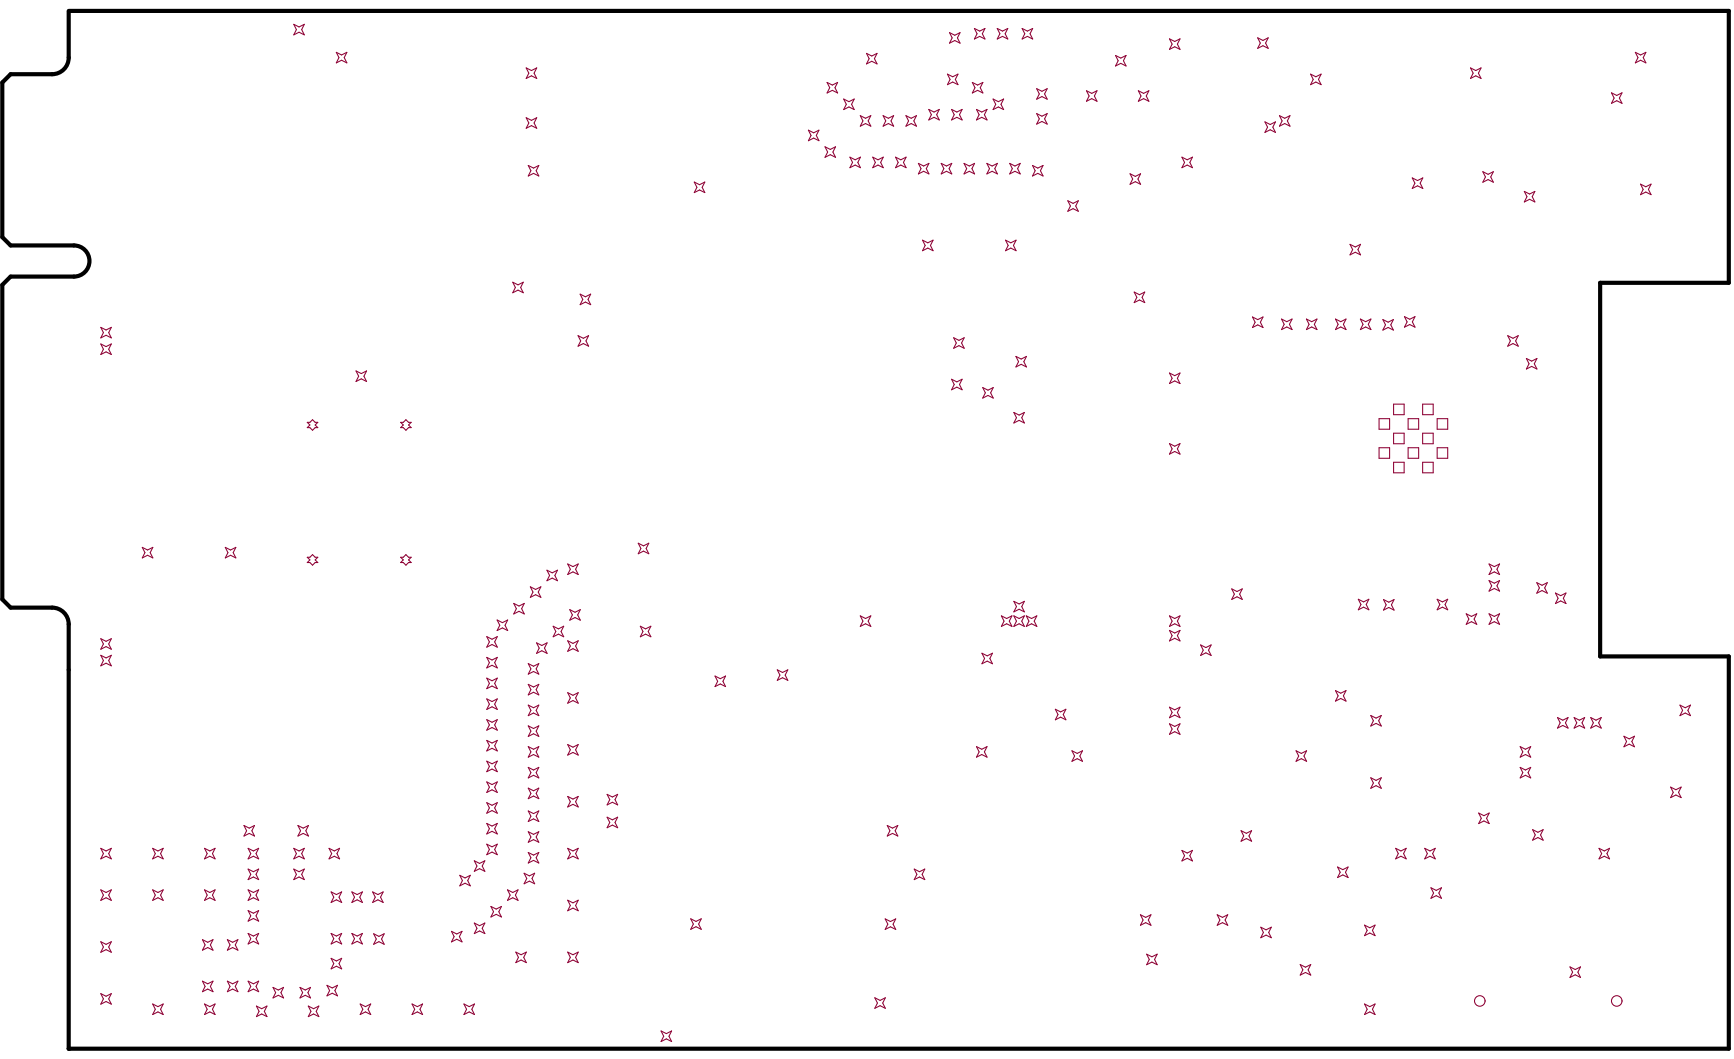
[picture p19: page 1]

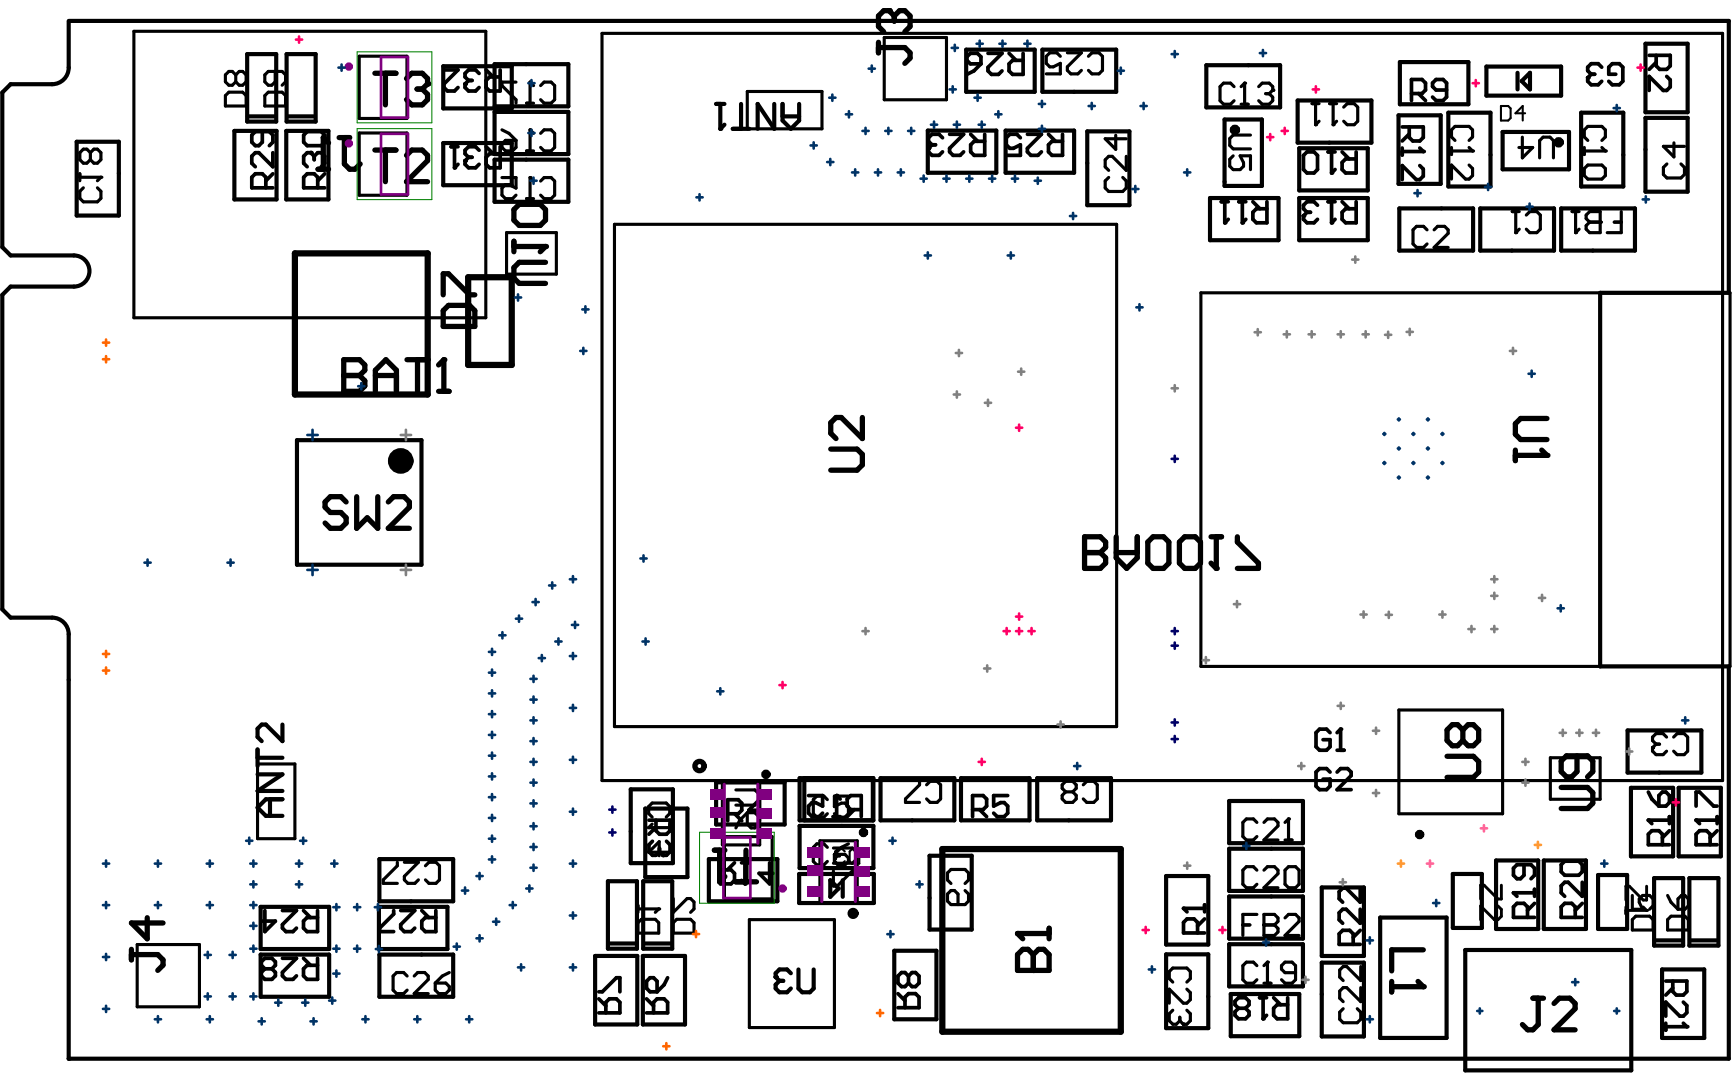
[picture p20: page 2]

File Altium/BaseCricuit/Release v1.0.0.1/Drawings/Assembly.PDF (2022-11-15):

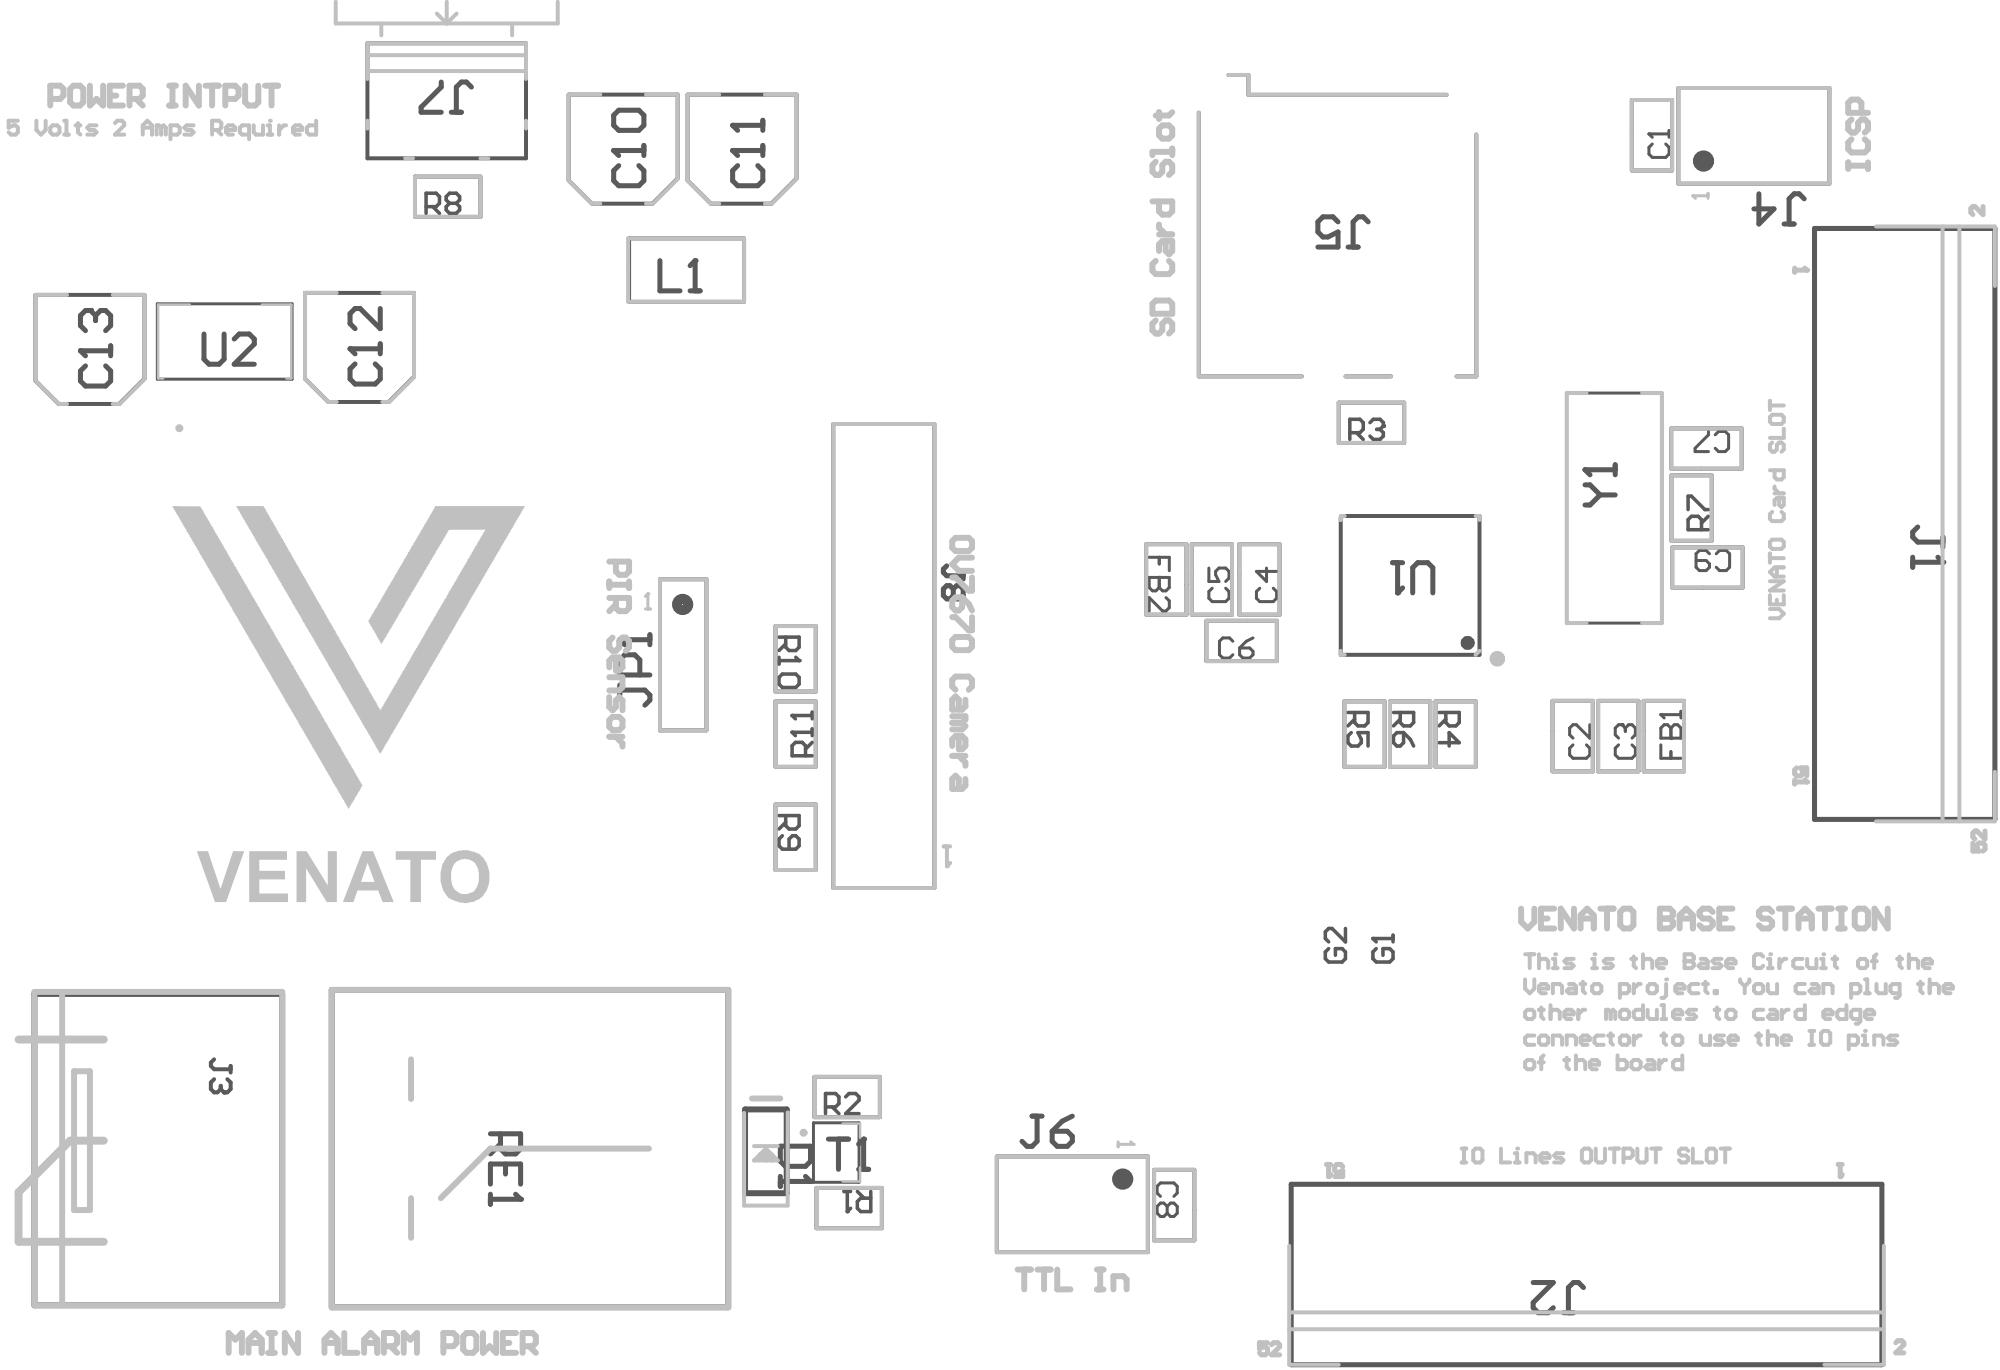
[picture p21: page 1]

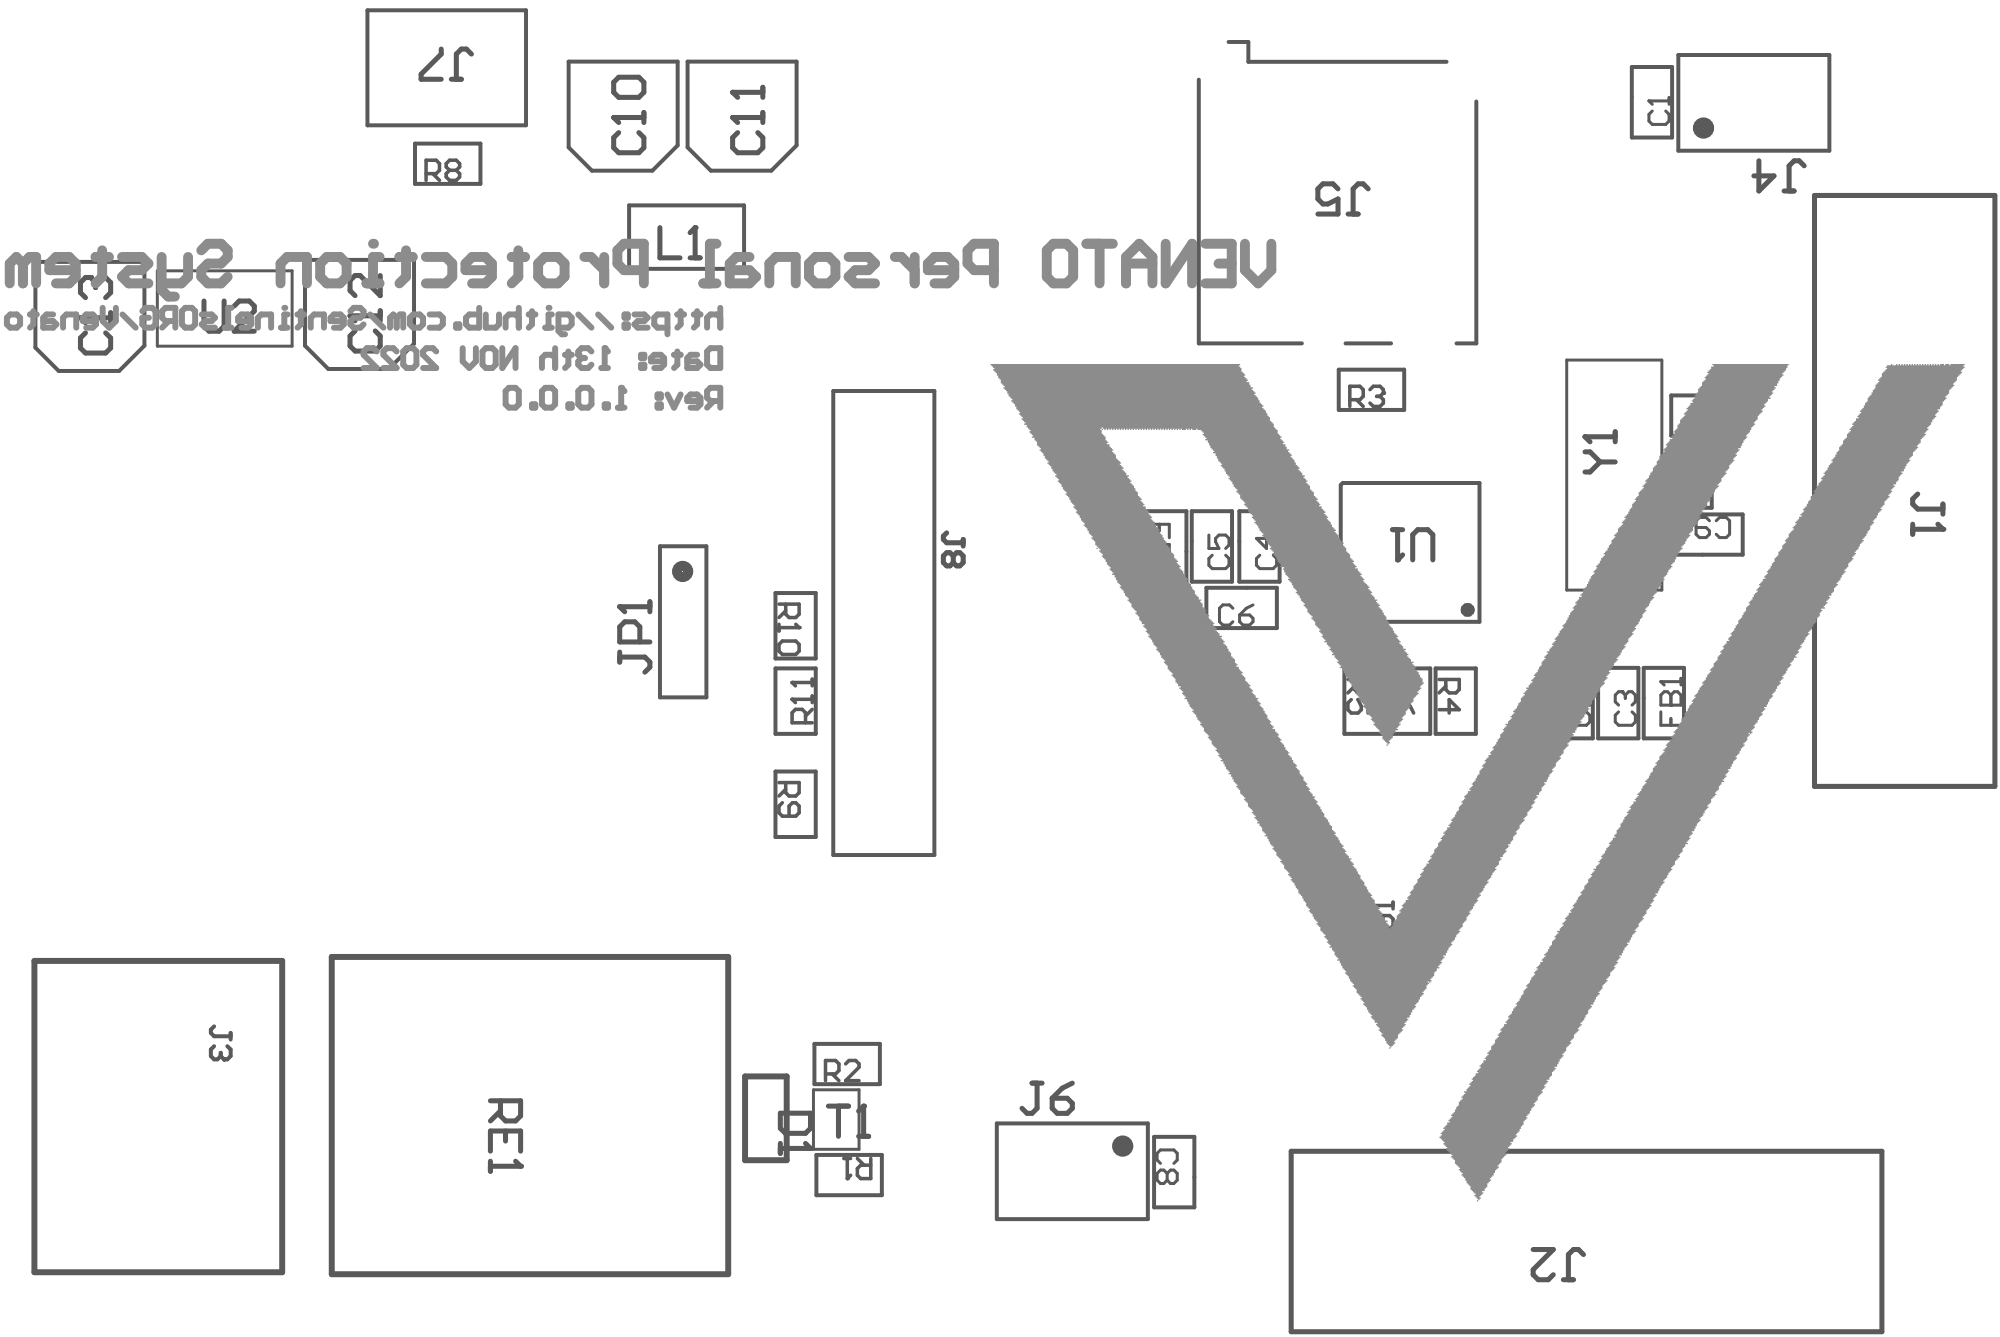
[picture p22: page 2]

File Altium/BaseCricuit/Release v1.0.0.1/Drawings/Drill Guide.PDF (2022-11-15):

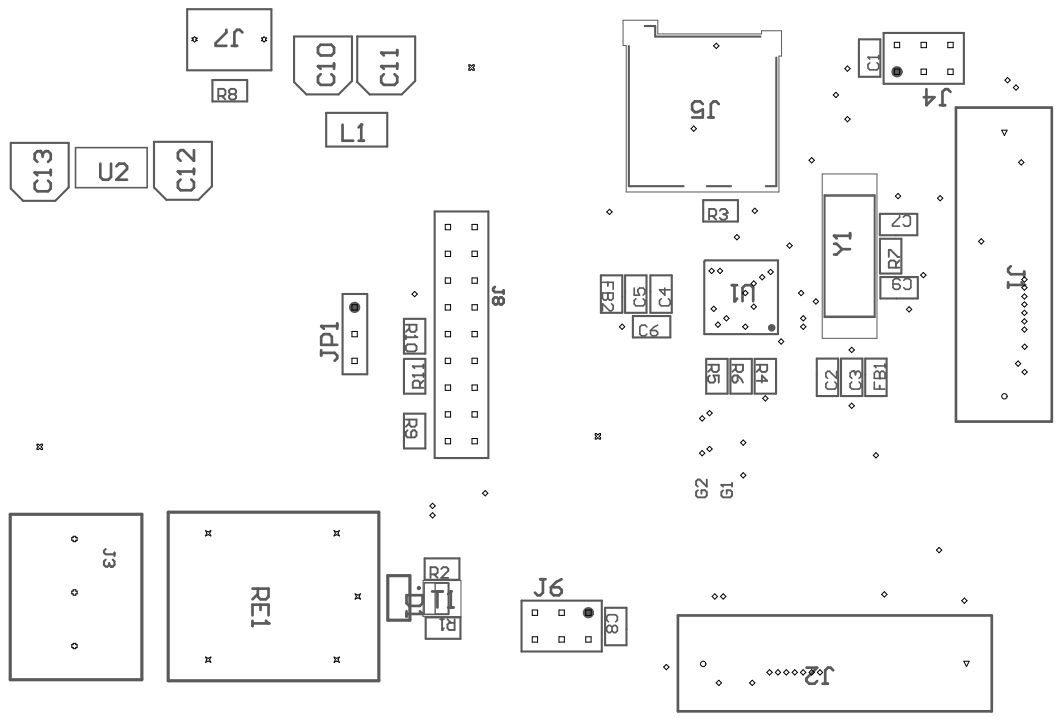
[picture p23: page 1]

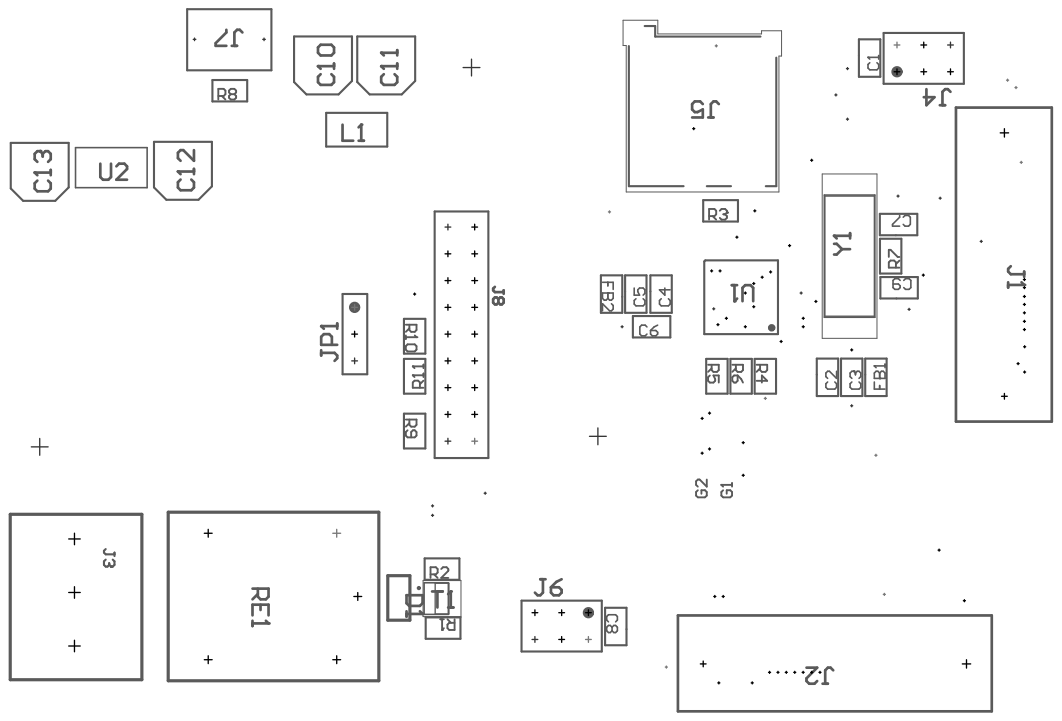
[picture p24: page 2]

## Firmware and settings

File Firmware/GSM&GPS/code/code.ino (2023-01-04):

#include <DFRobot_SIM808.h>
DFRobot_SIM808 sim808(&Serial);

//define the phone number
#define PHONE_NUMBER  "0779675524"
#define message
#define date
#define time 
#define location
#define speed
#define heading


void setup() {
  Serial.begin(9600);
  //******** Initialize sim808 module *************
  while(!sim808.init()) { 
      delay(1000);
      Serial.print("Sim808 init error\r\n");
  }
  Serial.println("Sim808 init success");

  //************* Turn on the GPS power************
  if( sim808.attachGPS())
      Serial.println("Open the GPS power success");
  else 
      Serial.println("Open the GPS power failure");
  

}

void loop() {
   //************** Get GPS data *******************
   if (sim808.getGPS()) {
     date= sim808.GPSdata.year + "/" +sim808.GPSdata.month + "/" + sim808.GPSdata.date + "/";
     time = sim808.GPSdata.hour + ":" +sim808.GPSdata.minute + ":" +sim808.GPSdata.second + "/n" ;
     location = "latitude :" + sim808.GPSdata.lat + "/n" + "longitude :" + sim808.GPSdata.lon ;
     speed =  "speed_kph :" + sim808.GPSdata.speed_kph ;
     hedaing = "heading :" + sim808.GPSdata.heading;
     message = date + time + location + speed + hedaing;
     sim808.sendSMS((char *)PHONE_NUMBER, (char *)message);

    //************* Turn off the GPS power ************
    sim808.detachGPS();

  }

}

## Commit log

2022-10-29 ADDITION: Initialized all files
    [Venato.PrjPcb, Venato_PCB_v1.PcbDoc, Venato_Schematic_v1.SchDoc]
2022-10-29 ADDITION: Added seperate schematic sheets for all members
    [chamith.SchDoc, saliya.SchDoc, sasmitha.SchDoc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]
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2022-10-30 ADDITION: Schematic sheets updated. and added components to schematic libs
    [schmaticSMDv1.SchLib, yasiru.SchDoc]
2022-10-30 Add 33pF,10pF caps to sch library
    [saliya.SchDoc, schmaticSMDv1.SchLib]
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2022-10-31 ADDITION: TP4052 component added
    [BaseCircuit.SchDoc, Venato.PrjPcb, schmaticSMDv1.SchLib]
2022-10-31 ADDITION: DW01A component created
    [schmaticSMDv1.SchLib]
2022-10-31 ADDITION: Base circuit project created and initialized
    [BaseCircuit.PcbDoc, BaseCircuit.SchDoc, BaseCricuit.PrjPcb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]
2022-10-31 ADDITION: 100 Ohm resistor added
    [BaseCircuit.PcbDoc, BaseCircuit.SchDoc, schmaticSMDv1.SchLib]
2022-10-31 ADDITION: Battery protection circuit is done and finished
    [BaseCircuit.PcbDoc, BaseCircuit.SchDoc, BaseCricuit.PrjPcb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]
2022-11-01 Add some components to libraries and updated the powerkey, sim and power module connections in scheamtics
    [saliya.SchDoc, schmaticSMDv1.SchLib]
2022-11-05 ADDITION: created parts and edited main schematic
    [Venato_Schematic_v1.SchDoc, schmaticSMDv1.SchLib]
2022-11-05 REMOVE: removed personal schematic sheets from the project
    [Venato.PrjPcb]
2022-11-05 ADDITION: Created other parts and made the schematic
    [Venato_Schematic_v1.SchDoc, schmaticSMDv1.SchLib]
2022-11-05 FINISHING: Revision 1 vas finished
    [Venato.PrjPcb, Venato_Schematic_v1.SchDoc, schmaticSMDv1.SchLib]
2022-11-05 INIT: Starting of PCB design
    [Venato_PCB_v1.PcbDoc, Venato_Schematic_v1.SchDoc, chamith.SchDoc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]
2022-11-05 PCB Placement stage 1 done
    [Venato_PCB_v1.PcbDoc, Venato_Schematic_v1.SchDoc, schmaticSMDv1.SchLib]
2022-11-05 PLACEMENT: USB placement done
    [Venato_PCB_v1.PcbDoc, Venato_Schematic_v1.SchDoc]
2022-11-05 PCB Placement stage 2 done
    [Venato_Schematic_v1.SchDoc]
2022-11-05 PCB Placement stage 3 done
    [Venato_Schematic_v1.SchDoc, schmaticSMDv1.SchLib]
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2022-11-06 Added 27nH inductor to libs
    [Venato_Schematic_v1.SchDoc, schmaticSMDv1.SchLib]
2022-11-06 Added 10 ohm resistor to libs
    [Venato_Schematic_v1.SchDoc, schmaticSMDv1.SchLib]
2022-11-06 Added IPEX and SMA connectors in Schematic libs for GSM and GPS antennas
    [Venato_Schematic_v1.SchDoc, schmaticSMDv1.SchLib]
2022-11-07 ROUTE: USB protocol routed
    [Venato_Schematic_v1.SchDoc]
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2022-11-07 ROUTING: Finishied for today
    [Venato.PrjPcb]
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2022-11-10 ADDITION: added many components and developed schematic sheets
    [Venato_Schematic_v1.SchDoc, schmaticSMDv1.SchLib, w3043.SLDPRT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]
2022-11-10 ADDITION: SMD Buzzer added
    [Venato_Schematic_v1.SchDoc, schmaticSMDv1.SchLib]
2022-11-10 ADDITION: ES36NC5M part added
    [Venato_Schematic_v1.SchDoc, schmaticSMDv1.SchLib]
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2022-11-10 ALL routed exept powerlines, antena feedlines and edge connector
    [Venato_Schematic_v1.SchDoc]
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2022-11-10 ROUTING: Polygon pour stage 1 done
    [Venato_Schematic_v1.SchDoc]
2022-11-11 Added Edge card footprint to PCB Libs. Ready to use
    [schmaticSMDv1.SchLib]
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2022-11-12 Added OV7670 and ESD diode array datasheets to datasheets folder
    [Saliya.SchDoc]
2022-11-12 ADDITION: ATMEGA328PB-AU part added
    [schmaticSMDv1.SchLib]
2022-11-12 SCHEMATIC: Base circuit schematic creating stage 1 done
    [BaseCircuit.PcbDoc, BaseCircuit.SchDoc, schmaticSMDv1.SchLib]
2022-11-12 BASE Circuit placement done
    [BaseCircuit.SchDoc]
2022-11-12 Added Crystal oscillator to PCB libs and base circuit schematic
    [BaseCircuit.SchDoc, schmaticSMDv1.SchLib]
2022-11-12 Base Circuit Schematic Done
    [BaseCircuit.SchDoc]
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2022-11-13 Added Job file to Venato
    [Bill of Materials-Venato.xlsx, Venato.PrjPcb]
2022-11-13 Added Job file to Base Circuit
    [Bill of Materials-BaseCricuit.xlsx]
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2022-11-13 VENATO DTR Line connected to ESP32
    [Final BOM List.csv, Final BOM List.xlsx, Venato_Schematic_v1.SchDoc]
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2022-11-14 BASE Circuit connection resettled
    [BaseCircuit.SchDoc, BaseCricuit.PrjPcb]
2022-11-15 RELEASE: Venato PCB Released
    [Bill of Materials-Venato.xlsx, Final BOM List.xlsx, Venato.PrjPcb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]
2022-11-15 RELEASE Base circuit v1.0.0.0
    [Bill of Materials-BaseCricuit.xlsx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]
2022-11-17 Updated Gerbers in base circuit
    [Bill of Materials-BaseCricuit.xlsx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]
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2022-12-26 Added: Bottom part of Venato 3d model started.
    [venato_bottom.SLDPRT]
2023-01-09 Modified : Base pcb's solidworks part modified
    [venato_bottom.SLDPRT]
2023-01-10 Added: PCB holder for venato.
    [venato_pcb_holder.SLDPRT]
2023-01-14 Modified : Venato bottom part solidworks
    [venato_bottom.SLDPRT, venato_pcb_holder.SLDPRT]
2023-01-15 Changed : Venato solidworks based shape changed
    [venato_bottom.SLDPRT]
2023-01-15 Stage one done for Venato enclosure.
    [venato_bottom.SLDPRT, venato_pcb_holder.SLDPRT, venato_top.SLDPRT]
2023-01-16 Added : Base circuit enclosure started.
    [Base_solidworks.SLDPRT]
2023-01-17 Base enclosure Halfway done
    [Base_solidworks.SLDPRT, venato_bottom.SLDPRT, venato_pcb_holder.SLDPRT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]
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2023-01-18 Added GPS antenna to enclosure
    [venato_bottom.SLDPRT, venato_pcb_holder.SLDPRT]
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
